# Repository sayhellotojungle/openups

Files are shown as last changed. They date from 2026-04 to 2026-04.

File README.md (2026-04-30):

# OpenUPS-ESP32S3

基于 ESP32-S3 的智能锂电池 UPS 控制系统，使用 BQ24780S 充电管理芯片与 BQ76920 电池监控芯片，支持 3-5 串锂离子/磷酸铁锂电池，12-19V 宽电压输入。

> **为什么不用铅酸 UPS？** 铅酸 UPS 待机功耗 10W+，体积笨重。本项目面向小功率主机、NAS、软路由、网络设备等场景，锂电池方案更小巧、更省电、更安静。

## 功能特性

### 核心功能

- **USB HID UPS** — ESP32-S3 原生 USB 接口，Windows/macOS/Linux 自动识别为标准 UPS 设备，支持低电量安全关机
- **充放电管理** — BQ24780S 充电控制，支持自适应充电电流、定时充电窗口（5 组周计划）、混合供电模式
- **电池管理** — BQ76920 电池监控，库仑计 SOC 计算、SOH 学习、自动均衡、多重保护（OV/UV/OCD/SCD/OT）
- **Web 仪表盘** — SPA 单页应用，macOS 风格 UI，实时 WebSocket 数据推送（3 秒间隔）
- **OTA 固件更新** — 网页拖拽上传固件，带签名校验，双分区安全升级
- **MQTT 集成** — Home Assistant 自动发现，支持 TLS 加密连接
- **Prometheus 监控** — `/metrics` 端点，可直接接入 Grafana

### 保护机制

| 保护类型 | 说明 |
|---|---|
| 过压保护 (OV) | 单体电压超阈值，切断充电 FET |
| 欠压保护 (UV) | 单体电压低于阈值，切断放电 FET |
| 过流保护 (OCD) | 放电电流超限 |
| 短路保护 (SCD) | 短路快速响应 |
| 过温保护 | 板载 + 环境温度双重检测 |
| 充电超时 | 防止异常长时间充电 |
| 系统状态机 | INIT → NORMAL → WARNING → CRITICAL 四级状态管理 |

## 硬件

### 关键参数

| 参数 | 值 |
|---|---|
| 输入电压 | 12-19V DC |
| 充电电流 | 最高 8128mA（BQ24780S） |
| 放电电流 | 最高 20A |
| 输入电流 | 最高 8064mA |
| 电池类型 | 3-5 串 Li-ion / LiFePO4 |
| 电流采样电阻 | 10mΩ（充电侧）/ 5mΩ（放电侧） |
| I2C 总线 | GPIO11(SDA) / GPIO12(SCL)，100kHz |

### ESP32 开发板

选择 **ESP32-S3 N16R8** 版本的开发板（16MB Flash / 8MB PSRAM）。插入时**注意核对引脚排列和插入方向**，反接可能损坏开发板或主板。

### 电池夹选择

电池组有条件的**尽量选择直接点焊成组**，接触电阻最小、最可靠。

如果使用电池夹，建议如下：

| 类型 | 材质 | 优缺点 |
|---|---|---|
| 插针电池夹 | 钢片 | 夹持力强，但**过紧**，拆装困难 |
| 贴片电池夹 | 铜材质 | 导电好，但**过松**，接触不可靠 |
| **贴片铜弹片 + 螺旋弹簧**（推荐） | 黄铜/紫铜 | 导电好，弹簧提供足够的回弹力，**推荐方案** |

推荐方案：[贴片铜弹片](https://item.taobao.com/item.htm?id=833701074625) + 线径 0.8mm × 外径 5mm × 长度 50mm 的螺旋弹簧配合使用。弹片负责导电，弹簧负责提供夹持力。

> **不建议使用钢片电池夹**，夹持力过大容易损伤电池外壳；纯铜弹片弹力不足，需要搭配螺旋弹簧。

### 硬件注意事项

- **电池选择** — 电池最好选择品质一致的，并保证初始电压一致。BQ76920 内置的平衡速度极慢，每天大概 20mV 不到。如果是大容量电池，要考虑在线路上增加外部平衡电路，BQ76920 也是支持的
- **R27、R66** — 正常情况下**不需要焊接**，这两个电阻用于选择 NTC 与隔离 I2C 芯片的供电源
- **I2C 隔离芯片** — PCB 设计使用 ISO1640BDR，也可以更换为 ISO1540DR。虽然 ISO1640 标称支持热拔插而 ISO1540 不支持，但实测 ISO1540DR 同样可以正常工作
- **SW_activate 按键** — 电池刚接入或 BQ76920 进入运输模式后，需要按下此按键一次激活芯片
- **SW_reset 按键** — 长按数秒进入 WiFi AP 模式（重置网络）；开机时持续按住则重新进入配置模式
- **H6、H7 跳线** — 使用 3S 电池需短接 H6，4S 电池需短接 H7（取决于电池串数），**请务必仔细确认后再上电**
- PCB 设计文件位于 `hardware/` 目录（EasyEDA Pro 格式）
- 3D 打印外壳基于贴片电路板设计，可直接打印使用（文件后续上传）

### 引脚定义

<details>
<summary>点击展开完整引脚表</summary>

| 功能 | GPIO | 说明 |
|---|---|---|
| **I2C** | | |
| I2C_SDA | 11 | I2C 数据线 |
| I2C_SCL | 12 | I2C 时钟线 |
| **BQ24780S** | | |
| ACOK | 13 | 电源适配器接入检测 |
| PROCHOT# | 14 | 芯片报警状态 |
| TB_STAT# | 15 | 混合供电状态 |
| IADP | 1 | 输入电流 ADC |
| IDCHG | 2 | 放电电流 ADC |
| PMON | 9 | 系统功率监控 ADC |
| **BQ76920** | | |
| ALERT | 16 | 电池管理报警中断 |
| I2C_VCC | 6 | I2C 隔离芯片供电控制 |
| **电压/温度** | | |
| INPUT_VOLTAGE | 4 | 输入电压（1:10 分压） |
| BATTERY_VOLTAGE | 5 | 电池电压（1:10 分压） |
| BOARD_TEMP | 7 | 板载温度（NTC 10K） |
| ENV_TEMP | 8 | 环境温度（NTC 10K） |
| TEMP_POWER | 21 | NTC 供电使能 |
| **LED 指示** | | |
| POWER_LED | 42 | 电源指示灯 |
| CHARGING_LED | 41 | 充电指示灯 |
| DISCHARGING_LED | 40 | 放电指示灯 |
| WIFI_FAIL_LED | 39 | WiFi 连接失败 |
| WIFI_OK_LED | 38 | WiFi 连接成功 |
| RGB_LED | 48 | WS2812B 可编程 RGB |
| **控制** | | |
| BUZZER | 18 | 蜂鸣器 |
| RESET_BTN | 17 | 重置按键（长按 2.5s+ 恢复出厂） |

</details>

## 快速开始

### 环境准备

1. 安装 [Arduino IDE](https://www.arduino.cc/en/software)
2. 安装 ESP32-S3 开发板支持包（Board Manager 搜索 `esp32`）
3. 安装所需库：

| 库名 | 用途 |
|---|---|
| ESPAsyncWebServer | 异步 Web 服务器 |
| AsyncTCP | 异步 TCP |
| ArduinoJson | JSON 序列化 |
| FastLED | WS2812B RGB LED |
| Preferences | NVS Flash 存储 |
| esp_task_wdt | 看门狗定时器 |
| **AsyncMQTT_ESP32** | MQTT 客户端（作者 khoih-prog，**请务必安装此版本**） |

> **注意**：MQTT 库请安装 **AsyncMQTT_ESP32**（作者 khoih-prog），不要安装其他 MQTT 库，API 不兼容。

### 编译烧录

1. 用 Arduino IDE 打开项目根目录的 `sketch_jan14a.ino`
2. 选择开发板：ESP32-S3 Dev Module，并按如下配置：

   | 选项 | 值 |
   |---|---|
   | USB CDC On Boot | **Disabled** |
   | Flash Mode | **QIO 80MHz** |
   | Flash Size | **16MB** |
   | Partition Scheme | **Custom**（使用项目自带的 `partitions.csv`） |
   | PSRAM | **OPI PSRAM** |
   | USB Mode | **USB-OTG** |

3. 编译并烧录

### OTA 更新

系统运行后，访问 `http://<设备IP>/update`，拖拽固件文件即可在线升级。固件需包含签名校验头。

## 首次使用

### 按键操作说明

| 按键 | 操作 | 效果 |
|---|---|---|
| **SW_activate** | 短按 | 激活 BQ76920（电池接入或退出运输模式后使用） |
| **SW_reset** | 长按数秒（运行中） | 重置网络配置，进入 WiFi AP 热点模式 |
| **SW_reset** | 开机时持续按住 | 重新进入初始配置模式（清除 NVS 配置） |

### 1. 硬件准备

1. 选择 **ESP32-S3 N16R8** 开发板，插入主板时注意引脚方向
2. 根据电池串数短接对应跳线：
   - 3S 电池 → 短接 **H6**
   - 4S 电池 → 短接 **H7**
   - 5S 电池 → 无需短接
3. 连接电池，按下 **SW_activate** 按键一次激活 BQ76920
4. 连接电源适配器（12-19V）

> **3S 电池用户注意**：3S 电池满电电压为 12.6V，如果使用 12V 电源适配器，由于充电芯片需要一定的压差才能工作，电池将无法充满。建议使用 **13V 左右**的电源适配器。当然，充不满也无大碍——锂电池保持 40%-80% 电量区间反而更有利于延长电池寿命。

### 2. 网络配置

刷机后首次启动（NVS 无配置时），系统自动进入配置模式：

1. 搜索并连接 WiFi 热点 **`OpenUPS-esp32`**（密码：`12345678`）
2. 浏览器访问 `http://192.168.4.1` 进入配置向导
3. 按向导依次配置：WiFi → 网络 → 电池参数 → 硬件 → MQTT（可选）
4. 配置完成后系统自动重启，连接到你配置的 WiFi 网络

> WiFi 热点密码可在代码中自行修改。如果需要重新进入配置模式，开机时**持续按住 SW_reset** 即可。

### 3. 电池保护参数配置

**系统启动后，务必在配置页面正确设置电池保护参数，所有单位均为 mV 和 mA：**

| 参数 | 说明 | 示例（3S NCM） |
|---|---|---|
| 电池串数 | 3 / 4 / 5 | 3 |
| 标称容量 | 电池标称容量 (mAh) | 2500 |
| 过压阈值 (OV) | 单体过压保护 (mV) | 4250 |
| 过压恢复 | 单体过压恢复 (mV) | 4150 |
| 欠压阈值 (UV) | 单体欠压保护 (mV) | 2800 |
| 欠压恢复 | 单体欠压恢复 (mV) | 3000 |
| 最大充电电流 | 充电电流上限 (mA) | 2000 |
| 最大放电电流 | 放电电流上限 (mA) | 5000 |
| 短路保护阈值 | 短路电流阈值 (mA) | 10000 |
| 过温阈值 | 过温保护温度 (°C) | 55 |

> **请务必根据你所使用的电池规格设置这些参数，错误的参数可能导致电池损坏或安全事故！**

## Web 界面

系统运行后，浏览器访问设备 IP 即可查看仪表盘：

- **状态总览** — SOC 进度条、电压/电流/温度、5 节电池电压（高亮最大/最小值）、均衡状态、充放电模式
- **BMS 状态** — 详细电池信息、电池电压统计、BQ76920 寄存器转储
- **电源状态** — 输入/输出功率、充电控制状态、BQ24780S 寄存器转储
- **系统配置** — WiFi、BMS 参数、充放电管理、定时充电窗口、硬件控制
- **ADC 校准** — 各 ADC 通道独立校准系数
- **固件升级** — OTA 在线更新

## API 接口

| 端点 | 方法 | 说明 |
|---|---|---|
| `/` | GET | Web 仪表盘 |
| `/api/status` | GET | 系统状态 JSON |
| `/api/bms` | GET | BMS 数据 JSON |
| `/api/power` | GET | 电源数据 JSON |
| `/metrics` | GET | Prometheus 文本格式指标 |
| `/api/calibration` | GET/POST | ADC 校准读写 |
| `/save` | POST | 保存配置 |
| `/firmware` | POST | OTA 固件上传 |
| `/bms/shipmode` | POST | 进入 BMS 运输模式 |
| `/ws` | WebSocket | 实时数据推送（3s 间隔） |

## 架构概览

```
┌─────────────────────────────────────────────────────────┐
│                    SystemManagement                      │
│              (FSM: INIT → NORMAL → WARNING → CRITICAL)  │
├──────────┬──────────┬──────────┬──────────┬─────────────┤
│   BMS    │  Power   │ Hardware │ WebServer│  WiFiManager│
│ (BQ76920)│(BQ24780S)│Interface │ + OTA    │   STA/AP    │
├──────────┴──────────┴──────────┴──────────┴─────────────┤
│                     EventBus (Pub/Sub)                   │
├─────────────────────────────────────────────────────────┤
│              Global State (Blackboard)                   │
│         System_Global_State (all telemetry)              │
├─────────────────────────────────────────────────────────┤
│            Driver Layer (I2C + CRC)                      │
│         BQ24780S Driver  |  BQ76920 Driver               │
└─────────────────────────────────────────────────────────┘
```

**额外服务：**
- **UPS HID Service** — USB HID 协议，主机识别为标准 UPS
- **MQTT Service** — Home Assistant 自动发现 + TLS 支持
- **ConfigManager** — NVS Flash 持久化所有配置

## 分区布局

| 分区 | 类型 | 大小 | 说明 |
|---|---|---|---|
| nvs | data | 20KB | 配置存储 |
| otadata | data | 8KB | OTA 数据 |
| app0 | app | 4.5MB | 固件槽 A |
| app1 | app | 4.5MB | 固件槽 B |
| coredump | data | 64KB | 崩溃转储 |
| spiffs | data | 6MB | 文件系统 |

## 目录结构

```
├── sketch_jan14a.ino          # 主程序入口
├── partitions.csv             # 分区表
├── src/
│   ├── bq24780s.h/.cpp        # BQ24780S 充电芯片驱动
│   ├── bq76920.h/.cpp         # BQ76920 电池监控驱动
│   ├── i2c_interface.h/.cpp   # I2C 通信（含 CRC）
│   ├── pins_config.h          # 引脚定义
│   ├── data_structures.h      # 数据结构定义
│   ├── hardware_interface.h/.cpp  # GPIO/ADC/LED/蜂鸣器/按键
│   ├── bms.h/.cpp             # 电池管理系统
│   ├── power_management.h/.cpp    # 充放电管理
│   ├── system_management.h/.cpp   # 系统状态机
│   ├── config_manager.h/.cpp  # NVS 配置管理
│   ├── web_server.h/.cpp      # HTTP/WebSocket/Prometheus/OTA
│   ├── WiFiManager.h/.cpp     # WiFi 管理
│   ├── event_bus.h            # 事件总线
│   ├── event_types.h          # 事件类型定义
│   ├── ups_hid_service.h/.cpp # USB HID UPS 服务
│   ├── mqtt_service.h/.cpp    # MQTT + HA 自动发现
│   ├── time_utils.h/.cpp      # NTP 时间管理
│   ├── utils.h/.cpp           # 工具函数
│   └── templates/             # Web UI 模板
│       ├── css_templates.h
│       ├── js_templates.h
│       └── page_templates.h
├── hardware/
│   └── ups.eprj2              # EasyEDA Pro 硬件设计文件
└── doc/                       # 芯片寄存器文档
```

## 已知限制

- 代码目前处于**测试版本**，部分功能尚未完善
- **暂时只支持三元锂电池（NCM/NCA）**，磷酸铁锂电池（LiFePO4）需要自行修改 `src/bms.h` 中的电压阈值与 SOC-OCV 电量对应表
- 硬件设计基于 EasyEDA Pro，暂无 KiCad 版本
- SOC 计算在电池首次使用时需要一次完整充放电循环进行校准

## 安全提示

> **本项目涉及锂电池充放电管理，操作不当可能存在安全风险。请确保你：**
> - 了解锂电池安全知识
> - 能够正确设置电池保护参数（OV/UV/OCD/SCD）
> - 有基本的电子电路调试能力
> - 能够承担实验风险
>
> 作者不对因使用本项目造成的任何损失负责。

## 参与贡献

欢迎提交 Issue 和 Pull Request！

AI 时代，人人都是高级程序员。无论是代码优化、Bug 修复、功能增强还是文档改进，都欢迎参与。

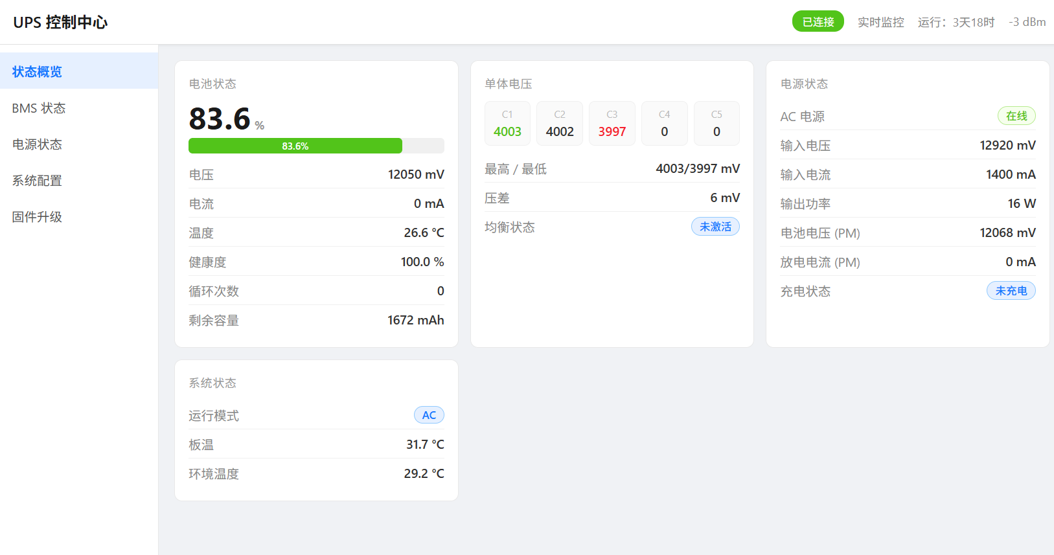
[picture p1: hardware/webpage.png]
webpage


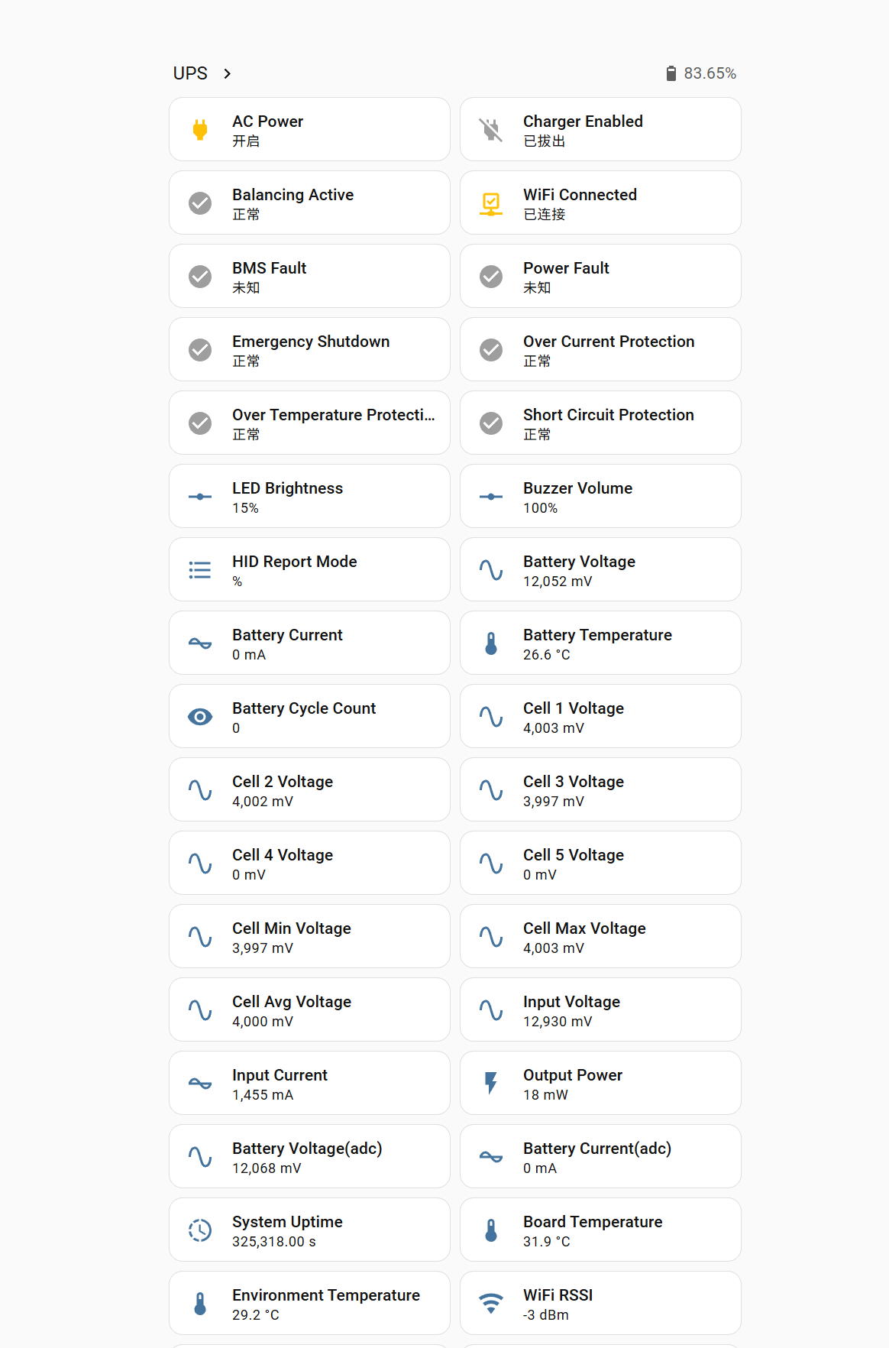
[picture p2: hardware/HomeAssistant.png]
HomeAssistant


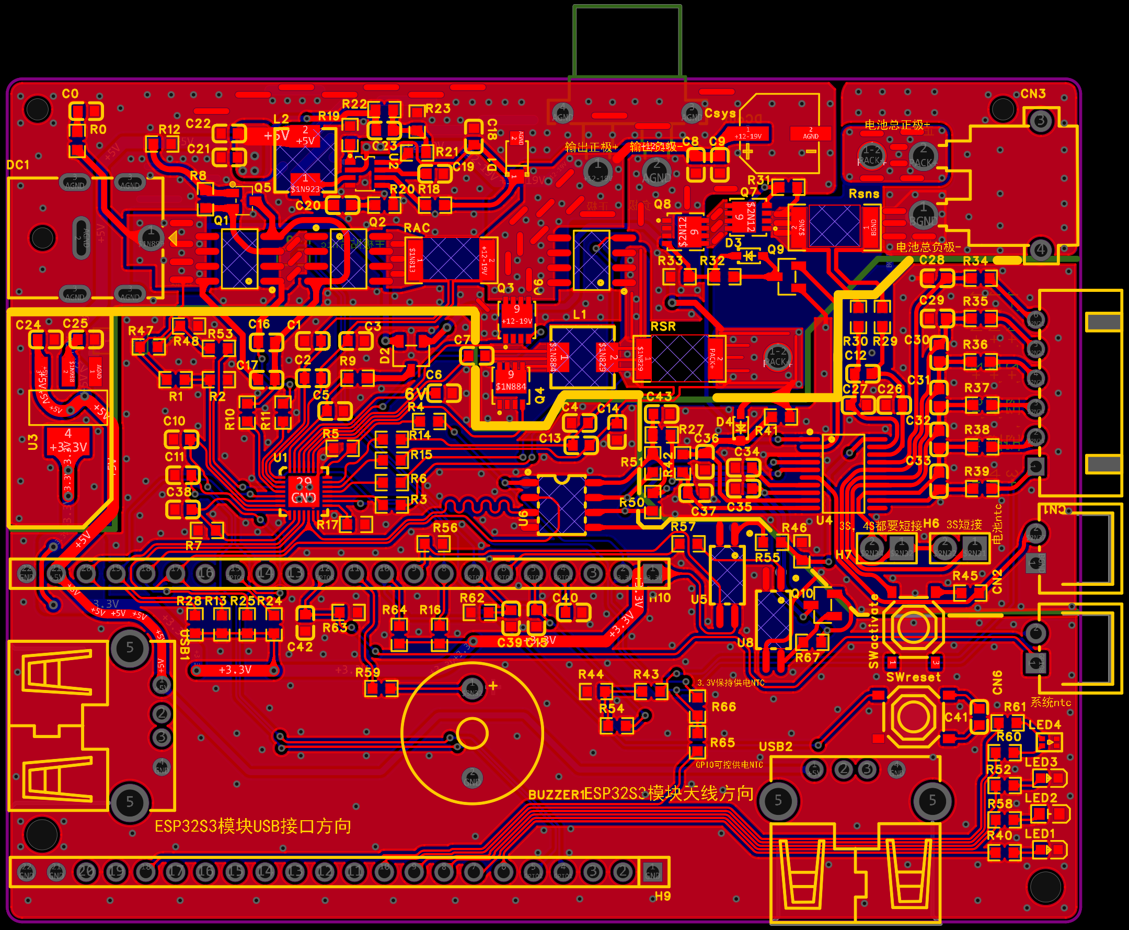
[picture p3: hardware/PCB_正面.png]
PCB_正面


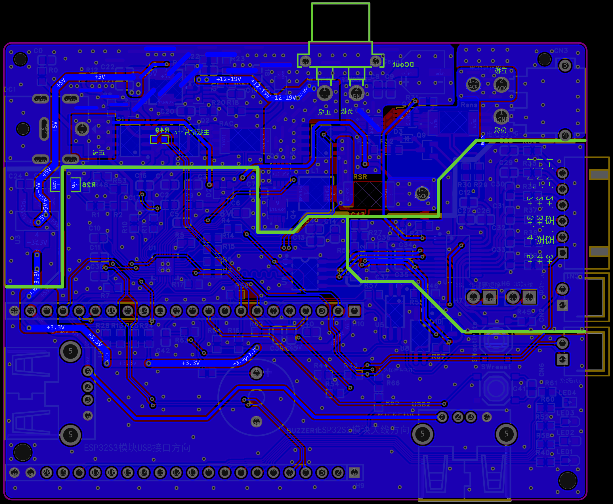
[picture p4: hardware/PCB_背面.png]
PCB_背面


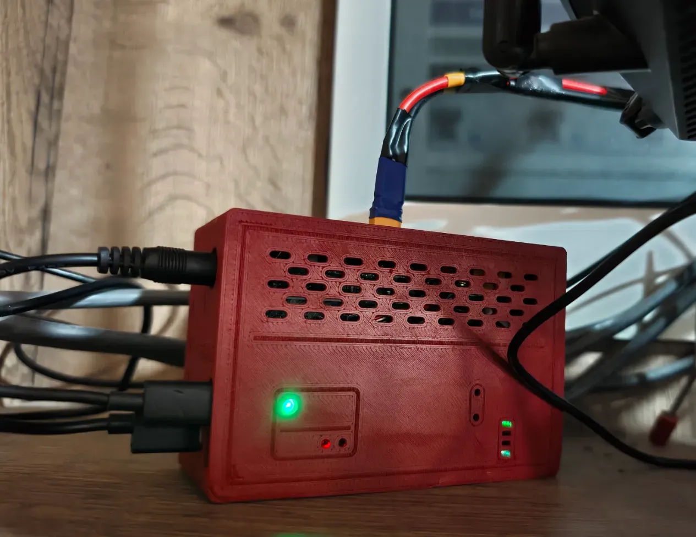
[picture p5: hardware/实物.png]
实物


实物1

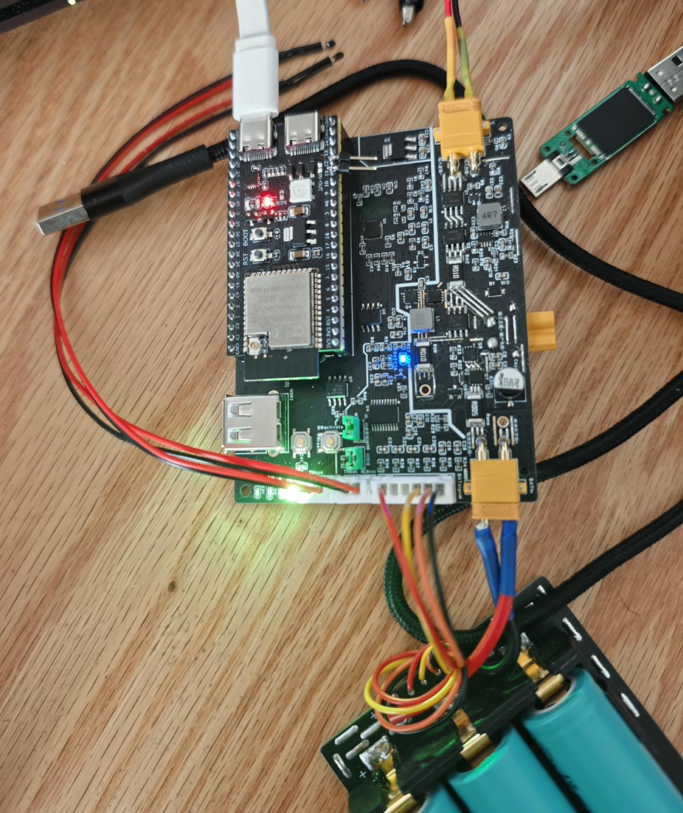
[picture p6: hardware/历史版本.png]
历史版本


## 致谢

本项目从硬件设计到嵌入式软件开发，几乎全部由 AI 辅助完成。作者此前没有任何硬件开发和嵌入式编程经验，没有 AI 的帮助，这个项目不可能实现。

特别感谢：

- **阿里巴巴通义千问（Qwen）**
- **小米 MiMo 大模型**

排名不分先后，都是伟大的公司！

AI 时代，人人都是高级程序员。

## 许可证

本项目为开源项目，详见仓库许可信息。

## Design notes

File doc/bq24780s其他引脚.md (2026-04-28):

这六个引脚（`ACOK`、`PROCHOT#`、`TB_STAT#`、`IADP`、`IDCHG`、`PMON`）主要负责**电源状态监控**、**系统保护**以及**CPU交互**。它们是 bq24780S 与主机系统（EC/BIOS）沟通电源健康状况的关键通道。

以下是基于文档的详细解释：

### 1. ACOK- 适配器正常指示

这是一个**输出信号**，用于告诉系统“适配器电源是否有效且稳定”。

- **功能**：适配器检测开漏输出（Open Drain Output）。
- **工作逻辑**：
  - **高电平（有效）**：当 `ACDET` 引脚电压高于 2.4V（且 `VCC` 在正常范围内，高于 UVLO 但低于过压值）时，内部 MOSFET 断开，引脚通过外部上拉电阻变高。这表示适配器已连接且电压正常，系统可以开启 ACFET 供电。
  - **低电平（无效）**：如果适配器电压过低、过高或未连接，内部 MOSFET 导通，引脚被拉低。
- **关键细节**：内部有一个约 150ms（首次插入）或 1.3s（后续插入）的延时（Debounce），防止插拔瞬间的抖动导致信号误判。

### 2. PROCHOT# - 处理器过热/过载指示

这是一个**输出信号**（低电平有效），用于通知 CPU 降低功耗（Throttling）。它是系统保护的最后一道防线。

- **功能**：开漏输出，主动向 CPU 发送“降频”请求。
- **触发条件**（任一满足即触发）：
  - **ICRIT**：适配器峰值电流超过设定值（默认 150%）。
  - **INOM**：适配器平均电流超过设定值（默认 110%）。
  - **IDCHG**：电池放电电流过大。
  - **VSYS**：系统电压过低（跌落）。
  - **事件**：适配器突然拔掉（ACOK 变低）或电池突然拔掉（BATPRES 变高）。
- **动作**：一旦触发，`PROCHOT#` 会拉低至少 **10ms**（默认），强制 CPU 降低频率以减少系统功耗，防止适配器过载或系统崩溃。

### 3. TB_STAT#  - 涡轮/升压模式状态

这是一个**输出信号**（低电平有效），用于指示芯片当前是否处于**混合动力升压模式**（Hybrid Power Boost Mode，文档中也称 Turbo Boost）。

- **功能**：升压模式指示。
- **状态含义**：
  - **低电平（Active）**：芯片正处于升压模式。这意味着系统需求功率超过了适配器的供应能力，电池正在放电以辅助供电。
  - **高电平（Inactive）**：芯片处于正常的充电模式（仅适配器供电）。
- **应用场景**：系统可以通过读取这个引脚的状态来判断是否处于高负载状态（如游戏或渲染时 CPU/GPU 满载）。

### 4. IADP  - 适配器电流监测输出

这是一个**模拟电压输出**，用于实时反映**输入电流**的大小。

- **功能**：适配器电流缓冲输出。
- **计算公式**：
  - VIADP=G×(VACP−VACN)*V**I**A**D**P*=*G*×(*V**A**CP*−*V**A**CN*)
  - **增益 (G)**：可通过 SMBus 在 20x 或 40x 之间选择（默认 20x）。
- **用途**：主机（EC）可以通过 ADC 读取这个电压，计算出当前从适配器取用了多少电流。用于系统功耗管理或在 `PROCHOT` 触发前进行预判。

### 5. IDCHG  - 电池放电电流监测输出

这是一个**模拟电压输出**，专门用于监测**电池放电**时的电流。

- **功能**：放电电流缓冲输出。
- **计算公式**：
  - VIDCHG=G×(VSRN−VSRP)
  - **增益 (G)**：可通过 SMBus 在 8x 或 16x 之间选择（默认 16x）。
- **用途**：
  - 监测电池当前是充电还是放电。
  - 在混合升压模式下，监测电池输出了多少电流。
  - 作为 `PROCHOT` 信号的触发源之一（防止电池放电过流）。

### 6. PMON  - 系统总功率监测输出

这是一个**模拟电流/电压输出**，用于反映系统的**总功率**。

- **功能**：系统功率监测。
- **工作原理**：
  - 引脚输出的是**电流**，通常需要外接一个电阻接地转换为电压。
  - 输出电流与“适配器输入功率”和“电池充放电功率”的总和成正比。
- **比例因子**：
  - 默认为 **1 μA/W**（可通过 SMBus 寄存器 `ChargeOption1` (0x3B) Bit 9 修改）。
  - 例如：当系统总功率为 45W 时，输出电流约为 45μA。若负载电阻为 100kΩ，则输出电压为 4.5V（需注意电压钳位在 3.3V 左右）。
- **用途**：提供系统总能耗数据，帮助系统进行更全面的功耗预算管理。

### ILIM --硬件限制充放电电流

| ILIM 电压 ( $ V_{ILIM} $ ) | 充电电流限制 ( $ I_{CHG} $ ) | 放电电流限制 ( $ I_{DIS} $ ) | 状态说明 |
| --- | --- | --- | --- |
| 0 mV - 60 mV | 0 A | 0 A | 禁止 (Converter Disabled) |
| 75 mV | 375 mA | 1.5 A | 软件限制优先于此值 |
| 100 mV | 500 mA | 2.0 A | 软件限制优先于此值 |
| 120 mV | 600 mA | 2.4 A | 开启阈值 (Converter Enable) |
| 200 mV | 1.0 A | 4.0 A | 典型限制值 |
| 400 mV | 2.0 A | 8.0 A | 常用限制值 |
| 500 mV | 2.5 A | 10.0 A | - |
| 800 mV | 4.0 A | 16.0 A | - |
| 1000 mV (1V) | 5.0 A | 20.0 A | - |
| 1600 mV (1.6V) | 8.0 A | 32.0 A | 放电上限 (Discharge Max) |
| > 2000 mV (2V) | 寄存器设定值 | 寄存器设定值 | 失效 (Disabled, 软件控制优先) |

### 总结表格

表格

| 引脚名称 | I/O类型 | 信号性质 | 核心功能 |
| :--- | :--- | :--- | :--- |
| **ACOK** | Output  | 数字 (开漏) | 适配器是否连接正常 |
| **PROCHOT#** | Output  | 数字 (低有效) | 紧急通知 CPU 降频 (过流/过压/欠压) |
| **TB_STAT#** | Output  | 数字 (低有效) | 指示是否处于“电池+适配器”同时供电模式 |
| **IADP** | Output  | 模拟电压 | 输出与适配器电流成比例的电压 |
| **IDCHG** | Output  | 模拟电压 | 输出与电池放电电流成比例的电压 |
| **PMON** | Output  | 模拟电流/电压 | 输出与系统总功率成比例的信号 |

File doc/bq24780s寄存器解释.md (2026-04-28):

### Table 4. Battery Charger Command Summary

| 地址  | 寄存器名称 | 表号 | 读/写 | 描述 | 复位状态 (POR State) |
| :---- | :--- | :--- | :--- | :--- | :--- |
| 0x12H | ChargeOption0() | Table 5  | Read or Write | Charge Options Control 0 | 0xE108H |
| 0x3BH | ChargeOption1() | Table 6  | Read or Write | Charge Options Control 1 | 0xC210H |
| 0x38H | ChargeOption2() | Table 7  | Read or Write | Charge Options Control 2 | 0x0384H |
| 0x37H | ChargeOption3() | Table 8  | Read or Write | Charge Options Control 3 | 0x1A40H |
| 0x3CH | ProchotOption0() | Table 9  | Read or Write | PROCHOT Options Control 0 | 0x4A54H |
| 0x3DH | ProchotOption1() | Table 10 | Read or Write | PROCHOT Options Control 1 | 0x8120H |
| 0x3AH | ProchotStatus() | Table 11 | Read Only | PROCHOT status | 0x0000H |
| 0x14H | ChargeCurrent() | Table 12 | Read or Write | 7-bit Charge Current Setting | 0x0000H |
| 0x15H | ChargeVoltage() | Table 13 | Read or Write | 11-bit Charge Voltage Setting | 0x0000H |
| 0x39H | DischargeCurrent() | Table 15 | Read or Write | 6-bit Discharge Current Setting | 0x1800H, or 6144mA |
| 0x3FH | InputCurrent() | Table 14 | Read or Write | 6-bit Input Current Setting | 0x1000H, or 4096mA |
| 0xFEH | ManufacturerID() | - | Read Only | Manufacturer ID | 0x0040H |
| 0xFFH | DeviceID() | - | Read Only | Device ID | 0x30H |

### 表5. ChargeOption0 寄存器 (0x12H)

| 位域 | 位名称 | 描述 |
| :--- | :--- | :--- |
| **[15]** | **Low Power Mode Enable**<br>(EN_LWPWR) | **0:** IC 仅在电池模式下以性能模式运行。PROCHOT、电流/功率监视器缓冲器和独立比较器遵循寄存器设置。<br>**1:** IC 仅在电池模式下以低功耗模式运行。当此位使能时，IC 处于最低静态电流。PROCHOT、放电电流监视器缓冲器、功率监视器缓冲器和独立比较器均被禁用。<br>**（复位后默认）** |
| **[14:13]** | **WATCHDOG 定时器调整**<br>(WDTMR_ADJ) | 设置连续 SMBus 写充电电压或充电电流命令之间的最大延迟。如果 IC 在看门狗时间段内未接收到对 REG0x14() 或 REG0x15() 的写操作，充电器转换器将停止以禁用充电和升压模式操作。过期后，定时器将在写入 REG0x14() 或 REG0x15() 时恢复。如果所有其他条件有效，充电或升压操作将恢复。<br>**00:** 禁用看门狗定时器<br>**01:** 启用，5 秒<br>**10:** 启用，88 秒<br>**11:** 启用看门狗定时器 (175 秒) **（复位后默认）** |
| **[12:10]** | **Reserved** | **0 - 保留** |
| **[9:8]** | **Switching Frequency**<br>(PWM_FREQ) | 转换器开关频率。<br>**00:** 600 kHz<br>**01:** 800 kHz **（复位后默认）**<br>**10:** 1 MHz<br>**11:** 保留 |
| **[7:6]** | **Reserved** | **0 - 保留** |
| **[5]** | **LEARN Mode Enable**<br>(EN_LEARN) | 电池 LEARN 模式使能。在 LEARN 模式下，ACFET 和 RBFET 关断，BATFET 导通。当 /BATPRES 为高电平时，IC 退出 LEARN 模式，此位被置回 0。当电池耗尽时，充电器无法使能 LEARN 模式。<br>**0:** 禁用 LEARN 模式 **（复位后默认）**<br>**1:** 使能 LEARN 模式 |
| **[4]** | **IADP Amplifier Gain for Primary Input**<br>(IADP_GAIN) | IADP 引脚电压与 ACP 和 ACN 之间电压的比值。<br>**0:** 20X **（复位后默认）**<br>**1:** 40X |
| **[3]** | **IDCHG Amplifier Gain**<br>(IDCHG_GAIN) | IDCHG 引脚电压与 SRN 和 SRP 之间电压的比值。<br>**0:** 8x，放电电流调节范围 0-32A。<br>**1:** 16x，放电电流调节范围 **（复位后默认）** |
| **[2:1]** | **Reserved** | **0 - 保留** |
| **[0]** | **Charge Inhibit**<br>(CHRG_INHIBIT) | 充电抑制。当此位为 0 时，如果 REG0x14() 和 REG0x15() 中有有效值，则使能电池充电。<br>**0:** 使能充电 **（复位后默认）**<br>**1:** 抑制充电 |

### 表6. ChargeOption1 寄存器 (0x3BH)

| 位域 | 位名称 | 描述 |
| :--- | :--- | :--- |
| **[15:14]** | **Battery Depletion Threshold**<br>(BAT_DEPL_VTH) | 电池欠压阈值。在 LEARN 周期中，当电池电压低于耗尽阈值时，IC 退出 LEARN 模式。在升压模式中，当电池电压低于耗尽阈值时，IC 退出升压模式。<br>**00:** 下降阈值 = 电压调节限制的 59.19% (~2.486V/电芯)<br>**01:** 下降阈值 = 电压调节限制的 62.65% (~2.631V/电芯)<br>**10:** 下降阈值 = 电压调节限制的 66.55% (~2.795V/电芯)<br>**11:** 下降阈值 = 电压调节限制的 70.97% (2.981V/电芯) **（复位后默认）** |
| **[13:12]** | **(RSNS_RATIO)** | 使用不同的输入采样电阻 RAC 和充电采样电阻 RSR 调整 PMON 计算。<br>**00:** RAC 和 RSR 1:1 **（复位后默认）**<br>**01:** RAC 和 RSR 2:1<br>**10:** RAC 和 RSR 1:2<br>**11:** 保留 |
| **[11]** | **EN_IDCHG** | IDCHG 引脚输出使能。<br>**0:** 禁用 IDCHG 输出以最小化静态电流 (Iq) **（复位后默认）**<br>**1:** 使能 IDCHG 输出 |
| **[10]** | **EN_PMON** | PMON 引脚输出使能。<br>**0:** 禁用 PMON 输出以最小化静态电流 (Iq) **（复位后默认）**<br>**1:** 使能 PMON 输出 |
| **[9]** | **PMON Gain**<br>(PMON_RATIO) | PMON 输出电流与总输入和电池功率的比率（使用 10 mΩ 采样电阻）。<br>**0:** 0.25 μA/W<br>**1:** 1 μA/W **（复位后默认）**<br>当采样电阻为 20/10 mΩ，或 10/20 mΩ，或 20/20 mΩ (RAC 和 RSR) 时：<br>**0:** 0.5 μA/W<br>**1:** 2 μA/W **（复位后默认）** |
| **[8]** | **Reserved** | **0 - 保留** |
| **[7]** | **Independent Comparator**<br>Reference (CMP_REF) | 独立比较器内部参考电压。<br>**0:** 2.3 V **（复位后默认）**<br>**1:** 1.2 V |
| **[6]** | **Independent Comparator**<br>Polarity (CMP_POL) | 独立比较器输出极性。<br>**0:** 当 CMPIN 高于内部阈值时，CMPOUT 为低电平 **（复位后默认）**<br>**1:** 当 CMPIN 高于内部阈值时，CMPOUT 为高电平 |
| **[5:4]** | **Independent Comparator**<br>Deglitch Time (CMP_DEG) | 独立比较器去抖时间，应用于 CMPOUT 变低的边沿。不适用于 CMPOUT 上升沿。<br>**00:** 禁用独立比较器<br>**01:** 使能独立比较器，输出去抖时间 1 μs **（复位后默认）**<br>**10:** 使能独立比较器，输出去抖时间 2 ms<br>**11:** 使能独立比较器，输出去抖时间 5 sec |
| **[3]** | **Power Path Latch-off Enable**<br>(EN_FET_LATCHOFF)  | 当独立比较器触发时，ACFET/RBFET 关断。锁定解除方式：上电复位 (POR) 或将此位写为 0。<br>**0:** 当独立比较器触发时，无电源路径锁定关闭 **（复位后默认）**<br>**1:** 当独立比较器触发时，电源路径锁定关闭。 |
| **[2]** | **Reserved** | **0 - 保留** |
| **[1]** | **Discharge SRN for Shipping Mode**<br>(EN_SHIP_DCHG) | 以最小 5-mA 电流为 SRN 引脚放电 140 ms。140 ms 后，此位被重置为 0。<br>**0:** 禁用放电模式 **（复位后默认）**<br>**1:** 使能放电模式 |
| **[0]** | **Reserved** | **0 - 保留** |

### 表7. ChargeOption2 寄存器 (0x38H)

| 位域 | 位名称 | 描述 |
| --- | --- | --- |
| **[15:10]** | **Reserved** | **0 – 保留** |
| **[9:8]** | **Reserved** | **1 - 保留** |
| **[7]** | **External Current Limit Enable** (EN_EXTILIM) | 外部 ILIM 引脚使能，用于设置充电和放电电流。 **0:** 充电/放电电流限制由 REG0x14() 和 REG0x39() 设置。 **1:** 充电/放电电流限制由 ILIM 引脚和寄存器设置的较低值决定。 **（复位后默认）** |
| **[6:3]** | **Reserved** | **0 - 保留** |
| **[2]** | **Reserved** | **1 - 保留** |
| **[1:0]** | **Reserved** | **0 - 保留** |

### 表8. ChargeOption3 寄存器 (0x37H)

| 位域 | 位名称 | 描述 |
| --- | --- | --- |
| **[15]** | **Discharge Current Regulation Enable** (EN_IDCHG_REG) | 电池放电电流调节使能。 **0:** 禁用放电电流调节 **（复位后默认）** **1:** 使能放电电流调节 |
| **[14:13]** | **Reserved** | **0 - 保留** |
| **[12]** | **ACOK Deglitch Time for Primary Input** (ACOK_DEG) | 调整 ACOK 上升沿去抖时间。 上电复位 (POR) 后，第一次插入适配器时，去抖时间始终为 150 ms，与寄存器位无关。从第二次插入适配器开始，去抖时间遵循位设置。当系统过流或系统短路导致 ACDET 被拉低至 2.4 V 以下时，1.3 秒去抖时间使 ACFET/RBFET 在下次开启前保持关闭足够长时间。 **0:** ACOK 上升沿去抖时间 150ms **1:** ACOK 上升沿去抖时间 1.3 sec **（复位后默认）** |
| **[11]** | **Adapter Present Indicator** (ACOK_STAT) | 输入存在指示。逻辑与 ACOK 引脚相同。此位为只读。 **0:** AC 适配器不存在 **1:** AC 适配器存在 |
| **[10]** | **ACOC Enable** (EN_ACOC) | 通过监测 ACP_ACN 电压进行 ACOC 保护。 **0:** 禁用 ACOC **（复位后默认）** **1:** 使能 ACOC |
| **[9]** | **ACOC Limit** (ACOC_VTH) | ACOC 保护阈值，通过监测 ACP_ACN 电压设置。 **0:** ICRIT 的 125% **1:** ICRIT 的 200% **（复位后默认）** |
| **[8]** | **Reserved** | **0 – 保留** |
| **[7]** | **HSFET VDS Threshold** (IFAULT_HI) | 通过监测高侧 MOSFET 漏源电压进行 MOSFET/电感短路保护。 **0:** 禁用 **（复位后默认）** **1:** 750 mV |
| **[6]** | **LSFET VDS Threshold** (IFAULT_LO) | 通过监测低侧 MOSFET 漏源电压进行 MOSFET/电感短路保护。也可作为升压功能期间的逐周期电流限制阈值。 **0:** 禁用 **1:** 250 mV **（复位后默认）** |
| **[5]** | **Fast DPM Threshold** (FDPM_VTH) | 快速 DPM 比较器阈值，用于进入混合电源升压模式。（升压模式的最小 DPM 设置：1536 mA） **0:** 107% (下降 93%) **（复位后默认）** **1:** 115% (下降 85%) |
| **[4:3]** | **Fast DPM Deglitch Time** (FDPM_DEG) | 从系统电流超过快速 DPM 阈值到电池放电进入升压模式的响应时间。 **00:** 响应时间 150 μs **（复位后默认）** **01:** 响应时间 250 μs **1X:** 响应时间 50 μs |
| **[2]** | **Hybrid Power Boost Mode Enable** (EN_BOOST) | 升压模式使能位。当 /BATPRES 从低电平变为高电平（电池移除）时，此位将被重置为零以禁用升压模式。 **0:** 禁用混合电源升压模式 **（复位后默认）** **1:** 使能混合电源升压模式 |
| **[1]** | **Boost Mode Indication** (BOOST_STAT) | 升压模式指示器。当设备处于升压模式时，此位变为低电平。此位为只读。 **0:** 充电器不在混合电源升压模式 **（复位后默认）** **1:** 充电器在混合电源升压模式 |
| **[0]** | **Reserved** | **0 – 保留** |

### 表9. ProchotOption0 寄存器 (0x3CH)

| 位域 | 位名称 | 描述 |
| --- | --- | --- |
| **[15:11]** | **ICRIT Threshold** (ICRIT_VTH) | 5 位，REG0x3F() 中 IDPM 的百分比。测量通过 ACP 和 ACN 的电流。当电流高于此阈值时触发。 **00000:** 110% **00001:** 110% **00010:** 115% **00011:** 120% …. **10010:** 195% **10011:** 200% **10100:** 205% **10101:** 210% **10110:** 215% **10111:** 220% **11000:** 225% **11001:** 230% **11010:** 250% **11011:** 300% **11100:** 350% **11101:** 400% **11110:** 450% **11111:** 超出范围 步进: 5%, 默认值: 150% (01001) |
| **[10:9]**  | **ICRIT Deglitch time** (ICRIT_DEG) | 典型 ICRIT 去抖时间。 **00:** 10 μs **01:** 100 μs **（复位后默认）** **10:** 400 μs **11:** 800 μs |
| **[8]** | **Reserved** | **0 – 保留** |
| **[7:6]** | **VSYS Threshold** (VSYS_VTH) | 在 SRN 上测量，固定 20-μs 去抖时间。当 SRN 电压低于阈值时触发。 如果 REG0x15() 编程值低于 VSYS 阈值，建议不要在 PROCHOT 配置中使能 VSYS。 **00:** 5.75 V **01:** 6 V **（复位后默认）** **10:** 6.25 V **11:** 6.5 V |
| **[5]** | **PROCHOT Pulse Extension Enable** (EN_PROCHOT_EXT) | 当脉冲扩展使能时，保持 PROCHOT 引脚电压为低电平，直到主机写 0x3C[2] = 0。 **0:** 禁用脉冲扩展 **（复位后默认）** **1:** 使能脉冲扩展 |
| **[4:3]** | **PROCHOT Pulse Width** (PROCHOT_WIDTH) | 当 REG0x3C[5]=0 时的最小 PROCHOT 脉冲宽度。 **00:** 100 μs **01:** 1 ms **10:** 10 ms **（复位后默认）** **11:** 5 ms |
| **[2]** | **PROCHOT Pulse Clear** (PROCHOT_CLEAR) | 当 (0x3C[5] = 1) 时清除 PROCHOT 脉冲。 **0:** 清除 PROCHOT 脉冲并将 PROCHOT 引脚驱动为高电平 **1:** 空闲 **（复位后默认）** |
| **[1]** | **INOM Deglitch Time** (INOM_DEG) | 最大 INOM 去抖时间。INOM 阈值是 REG0x3F() 中 IDPM 的 110%。测量 ACP 和 ACN 之间的电流。当电流高于此阈值时触发。 **0:** 1 ms (必须是最大值) **（复位后默认）** **1:** 60 ms (最大值) |
| **[0]** | **Reserved** | **0 - 保留** |

### 表10. ProchotOption1 寄存器 (0x3DH)

| 位域 | 位名称 | 描述 |
| --- | --- | --- |
| **[15:10]** | **IDCHG Threshold** (IDCHG_VTH) | 6 位，范围 0 A 至 32256 mA，步进 512 mA。测量 SRN 和 SRP 之间的电流。当放电电流高于阈值时触发。 **默认:** 16384 mA (100000) |
| **[9:8]** | **IDCHG Deglitch Time** (IDCHG_DEG) | 典型 IDCHG 去抖时间。 **00:** 1.6 ms **01:** 100 μs **（复位后默认）** **10:** 6 ms **11:** 12 ms |
| **[7]** | **Reserved** | **0 - 保留** |
| **[6:0]** | **PROCHOT input current envelop selector** (PROFILE) | 当适配器存在时，PROCHOT 功能由以下位使能。 当适配器移除时，PROCHOT 配置中的 ICRIT、INOM、BATPRES 和 ACOK 功能自动禁用。比较器、IDCHG 和 VSYS 功能设置保留。当所有位为 0 时，PROCHOT 功能禁用。 **位 6:** 独立比较器, 0: 禁用 **（复位后默认）**; 1: 使能 **位 5:** ICRIT, 0: 禁用; 1: 使能 **（复位后默认）** **位 4:** INOM, 0: 禁用 **（复位后默认）**; 1: 使能 **位 3:** IDCHG, 0: 禁用 **（复位后默认）**; 1: 使能 **位 2:** VSYS, 0: 禁用 **（复位后默认）**; 1: 使能 **位 1:** BATPRES, 0: 禁用 **（复位后默认）**; 1: 使能 (单次上升沿触发) **位 0:** ACOK, 0: 禁用 **（复位后默认）**; 1: 使能 (单次下降沿触发) |

### 表11. ProchotStatus 寄存器 (0x3AH)

| 位域 | 位名称 | 描述 |
| --- | --- | --- |
| **[15:7]** | **Reserved** | **0 - 保留** |
| **[6:0]**  | **PROCHOT status** (Read only) | 在同一 PROCHOT 脉冲期间触发的所有事件的状态均设置为 1。寄存器在以下任一条件发生时重置： • 主机在 PROCHOT 变高后首次读取 • PROCHOT 变低以开始另一个脉冲。 **位 6:** 独立比较器, 0: 未触发; 1: 触发 **位 5:** ICRIT, 0: 未触发; 1: 触发 **位 4:** INOM, 0: 未触发; 1: 触发 **位 3:** IDCHG, 0: 未触发; 1: 触发 **位 2:** VSYS, 0: 未触发; 1: 触发 **位 1:** BATPRES, 0: 未触发; 1: 触发 **位 0:** ACOK, 0: 未触发; 1: 触发 |

### 表12. Charge Current 寄存器 (0x14H)，使用 10-mΩ 采样电阻

| 位域 | 位名称 | 描述 |
| --- | --- | --- |
| **0**  | Not used | 值忽略 |
| **1**  | Not used | 值忽略 |
| **2**  | Not used | 值忽略 |
| **3**  | Not used | 值忽略 |
| **4**  | Not used | 值忽略 |
| **5**  | Not used | 值忽略 |
| **6**  | **Charge Current, DACICHG 0** | 0 = 增加 0 mA 的充电器电流 1 = 增加 64 mA 的充电器电流 |
| **7**  | **Charge Current, DACICHG 1** | 0 = 增加 0 mA 的充电器电流 1 = 增加 128 mA 的充电器电流  |
| **8**  | **Charge Current, DACICHG 2** | 0 = 增加 0 mA 的充电器电流 1 = 增加 256 mA 的充电器电流  |
| **9**  | **Charge Current, DACICHG 3** | 0 = 增加 0 mA 的充电器电流 1 = 增加 512 mA 的充电器电流  |
| **10** | **Charge Current, DACICHG 4** | 0 = 增加 0 mA 的充电器电流 1 = 增加 1024 mA 的充电器电流 |
| **11** | **Charge Current, DACICHG 5** | 0 = 增加 0 mA 的充电器电流 1 = 增加 2048 mA 的充电器电流 |
| **12** | **Charge Current, DACICHG 6** | 0 = 增加 0 mA 的充电器电流 1 = 增加 4096 mA 的充电器电流 |
| **13** | Not used | 1 = 无效写入 |
| **14** | Not used | 1 = 无效写入 |
| **15** | Not used | 1 = 无效写入 |

### 表13. Charge Voltage 寄存器 (0x15H)

| 位域 | 位名称 | 描述 |
| --- | --- | --- |
| **0**  | Not used | 值忽略 |
| **1**  | Not used | 值忽略 |
| **2**  | Not used | 值忽略 |
| **3**  | Not used | 值忽略 |
| **4**  | **Charge voltage, DACV 0**  | 0 = 增加 0 mV 的充电器电压 1 = 增加 16 mV 的充电器电压 |
| **5**  | **Charge voltage, DACV 1**  | 0 = 增加 0 mV 的充电器电压 1 = 增加 32 mV 的充电器电压 |
| **6**  | **Charge voltage, DACV 2**  | 0 = 增加 0 mV 的充电器电压 1 = 增加 64 mV 的充电器电压 |
| **7**  | **Charge voltage, DACV 3**  | 0 = 增加 0 mV 的充电器电压 1 = 增加 128 mV 的充电器电压 |
| **8**  | **Charge voltage, DACV 4**  | 0 = 增加 0 mV 的充电器电压 1 = 增加 256 mV 的充电器电压 |
| **9**  | **Charge voltage, DACV 5**  | 0 = 增加 0 mV 的充电器电压 1 = 增加 512 mV 的充电器电压 |
| **10** | **Charge voltage, DACV 6**  | 0 = 增加 0 mV 的充电器电压 1 = 增加 1024 mV 的充电器电压  |
| **11** | **Charge voltage, DACV 7**  | 0 = 增加 0 mV 的充电器电压 1 = 增加 2048 mV 的充电器电压  |
| **12** | **Charge voltage, DACV 8**  | 0 = 增加 0 mV 的充电器电压 1 = 增加 4096 mV 的充电器电压  |
| **13** | **Charge voltage, DACV 9**  | 0 = 增加 0 mV 的充电器电压 1 = 增加 8192 mV 的充电器电压  |
| **14** | **Charge voltage, DACV 10** | 0 = 增加 0 mV 的充电器电压 1 = 增加 16384 mV 的充电器电压 |
| **15** | Not used | 1 = 无效写入 |

### 表14. Input Current 寄存器 (0x3FH)，使用 10-mΩ 采样电阻

| 位域 | 位名称 | 描述 |
| --- | --- | --- |
| **0**  | Not used | 值忽略 |
| **1**  | Not used | 值忽略 |
| **2**  | Not used | 值忽略 |
| **3**  | Not used | 值忽略 |
| **4**  | Not used | 值忽略 |
| **5**  | Not used | 值忽略 |
| **6**  | Not used | 值忽略 |
| **7**  | **Input current, DACIIN 0** | 0 = 增加 0 mA 的输入电流 1 = 增加 128 mA 的输入电流  |
| **8**  | **Input current, DACIIN 1** | 0 = 增加 0 mA 的输入电流 1 = 增加 256 mA 的输入电流  |
| **9**  | **Input current, DACIIN 2** | 0 = 增加 0 mA 的输入电流 1 = 增加 512 mA 的输入电流  |
| **10** | **Input current, DACIIN 3** | 0 = 增加 0 mA 的输入电流 1 = 增加 1024 mA 的输入电流 |
| **11** | **Input current, DACIIN 4** | 0 = 增加 0 mA 的输入电流 1 = 增加 2048 mA 的输入电流 |
| **12** | **Input current, DACIIN 5** | 0 = 增加 0 mA 的输入电流 1 = 增加 4096 mA 的输入电流 |
| **13** | Not used | 1 = 无效写入 |
| **14** | Not used | 1 = 无效写入 |
| **15** | Not used | 1 = 无效写入 |

### 表15. Discharge Current 寄存器 (0x39H)，使用 10-mΩ 采样电阻

| 位域 | 位名称 | 描述 |
| --- | --- | --- |
| **0**  | Not used | 值忽略 |
| **1**  | Not used | 值忽略 |
| **2**  | Not used | 值忽略 |
| **3**  | Not used | 值忽略 |
| **4**  | Not used | 值忽略 |
| **5**  | Not used | 值忽略 |
| **6**  | Not used | 值忽略 |
| **7**  | Not used | 值忽略 |
| **8**  | Not used | 值忽略 |
| **9**  | **Discharge current, DACIIN 0** | 0 = 增加 0 mA 的放电电流 1 = 增加 512 mA 的放电电流 |
| **10** | **Discharge current, DACIIN 1** | 0 = 增加 0 mA 的放电电流 1 = 增加 1024 mA 的放电电流  |
| **11** | **Discharge current, DACIIN 2** | 0 = 增加 0 mA 的放电电流 1 = 增加 2048 mA 的放电电流  |
| **12** | **Discharge current, DACIIN 3** | 0 = 增加 0 mA 的放电电流 1 = 增加 4096 mA 的放电电流  |
| **13** | **Discharge current, DACIIN 4** | 0 = 增加 0 mA 的放电电流 1 = 增加 8192 mA 的放电电流  |
| **14** | **Discharge current, DACIIN 5** | 0 = 增加 0 mA 的放电电流 1 = 增加 16384 mA 的放电电流 |
| **15** | Not used | 1 = 无效写入 |

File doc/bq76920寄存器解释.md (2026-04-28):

### 1. 系统状态与控制寄存器 (System Status & Control)

这些寄存器用于监控芯片状态、清除故障以及控制 MOS 管和 ADC 的开关。

| 寄存器名称  | 地址 | 位 (Bit) | 名称 | 读/写 | 复位值 | 功能详解 |
| --- | ---- | --- | --- | ----- | --- | --- |
| SYS_STAT | 0x00 | 7 | CC_READY | RW | 0 | 库仑计数器就绪。1=新的电流积分数据已准备好；0=无新数据。需写1清除。 |
| | | 6 | RSVD | - | 0 | 保留，勿用。 |
| | | 5 | DEVICE_XREADY | RW | 0 | 内部芯片故障。1=检测到内部逻辑错误（通常由瞬态干扰引起）。需写1清除。 |
| | | 4 | OVRD_ALERT | RW | 0 | ALERT 引脚外部强制。1=ALERT 引脚被外部电路拉高（如二级保护IC）。需写1清除。 |
| | | 3 | UV | RW | 0 | 欠压故障。1=检测到电池欠压。需写1清除。清除后需重新开启 DSG。 |
| | | 2 | OV | RW | 0 | 过压故障。1=检测到电池过压。需写1清除。清除后需重新开启 CHG。 |
| | | 1 | SCD | RW | 0 | 放电短路故障。1=检测到短路。需写1清除。清除后需重新开启 DSG。 |
| | | 0 | OCD | RW | 0 | 放电过流故障。1=检测到过流。需写1清除。清除后需重新开启 DSG。 |
| CELLBAL1 | 0x01 | 7-5 | RSVD | R | 0 | 保留。 |
| (均衡控制1) | | 4-0 | CB5-CB1 | RW | 0 | 电芯均衡开关。1=开启对应电芯 (Cell 1~5) 的均衡；0=关闭。 |
| SYS_CTRL1 | 0x04 | 7 | LOAD_PRESENT  | R | 0 | 负载存在检测。仅当 CHG_OFF 时有效。1=CHG 引脚被外部拉高，说明负载仍连接在 PACK- 上。 |
| (系统控制1) | | 6-5 | RSVD | R | 0 | 保留。 |
| | | 4 | ADC_EN | RW | 0 | ADC 使能。1=开启电压/温度测量（同时开启 OV/UV 保护）；0=关闭以省电。 |
| | | 3 | TEMP_SEL | RW | 0 | 温度源选择。0=读取内部芯片温度；1=读取外部热敏电阻 (TSx) 温度。 |
| | | 2 | RSVD | RW | 0 | 保留，必须写 0。 |
| | | 1-0 | SHUT_A/B | RW | 0 | 关机序列控制。进入 SHIP 模式需按特定顺序写入： 1. 写 `0x02` (A=0, B=1) 2. 写 `0x04` (A=1, B=0)。 |
| SYS_CTRL2 | 0x05 | 7 | DELAY_DIS | RW | 0 | 禁用保护延时。1= bypass OV/UV/OCD/SCD 的延时逻辑（用于产线快速测试），故障立即触发。正常使用时应为 0。 |
| (系统控制2) | | 6 | CC_EN | RW | 0 | 库仑计数器常开。1=持续进行电流积分；0=关闭常开模式。 |
| | | 5 | CC_ONESHOT | RW | 0 | 单次电流测量。1=触发一次 250ms 的电流测量，完成后自动清零。仅在 CC_EN=0 时有效。 |
| | | 4-2 | RSVD | RW | 0 | 保留，必须写 0。 |
| | | 1 | DSG_ON | RW | 0 | 放电 MOS 管控制。1=开启放电通路；0=关闭。故障发生后不会自动恢复，需软件写入 1。 |
| | | 0 | CHG_ON | RW | 0 | 充电 MOS 管控制。1=开启充电通路；0=关闭。故障发生后不会自动恢复，需软件写入 1。 |

### 2. 保护配置寄存器 (Protection Configuration)

用于设置过流、短路的阈值和延时，以及过压、欠压的阈值和延时。

| 寄存器名称 | 地址 | 位 (Bit) | 名称 | 功能详解 |
| --- | ---- | --- | --- | --- |
| PROTECT1 | 0x06 | 7 | RSNS | 量程倍增。0=低量程 (OCD/SCD 阈值较低)；1=高量程 (阈值 x2)。 配合下方阈值位使用。 |
| (短路保护1) | | 6 | RSVD | 保留。 |
| | | 5 | RSVD | 保留。 |
| | | 4-3 | SCD_DELAY  | 短路延时设置: `00`=70µs, `01`=100µs, `10`=200µs, `11`=400µs。 |
| | | 2-0 | SCD_THRESH | 短路阈值设置 (单位 mV，取决于 RSNS 位): 若 RSNS=0: `000`=22mV ... `111`=100mV 若 RSNS=1: `000`=44mV ... `111`=200mV |
| PROTECT2 | 0x07 | 7 | RSVD | 保留。 |
| (过流保护2) | | 6-4 | OCD_DELAY  | 过流延时设置: `000`=8ms ... `111`=1280ms (具体查表，呈倍数增长)。 |
| | | 3-0 | OCD_THRESH | 过流阈值设置 (单位 mV，取决于 RSNS 位): 若 RSNS=0: `0000`=8mV ... `1111`=50mV 若 RSNS=1: `0000`=17mV ... `1111`=100mV |
| PROTECT3 | 0x08 | 7-6 | UV_DELAY | 欠压延时设置: `00`=1s, `01`=4s, `10`=8s, `11`=16s。 |
| (压延保护延时) | | 5-4 | OV_DELAY | 过压延时设置: `00`=1s, `01`=2s, `10`=4s, `11`=8s。 |
| | | 3-0 | RSVD | 保留，保持默认。 |
| OV_TRIP | 0x09 | 7-0 | OV_THRESH  | 过压阈值中间8位。 实际阈值为 `10` + [这8位] + `1000` (共14位 ADC 值)。 需结合 ADCGAIN/OFFSET 计算具体电压值 (约 3.15V~4.7V)。默认 0xAC。 |
| UV_TRIP | 0x0A | 7-0 | UV_THRESH  | 欠压阈值中间8位。 实际阈值为 `01` + [这8位] + `0000` (共14位 ADC 值)。 需结合 ADCGAIN/OFFSET 计算具体电压值 (约 1.58V~3.1V)。默认 0x97。 |
| CC_CFG | 0x0B | 7-6 | RSVD | 保留。 |
| (CC 配置) | | 5-0 | CC_CFG | 必须写入 0x19 以获得最佳库仑计数器性能。 |

### 3. 数据读取寄存器 (Data Readout Registers)

这些寄存器只读，存储最新的测量数据。读取时应连续读取 HI 和 LO 字节。

| 寄存器组 | 地址范围 | 说明 |
| --- | --- | --- |
| VC1 ~ VC5 | 0x0C - 0x15 | 电芯电压 1-5。每节电芯占用 2 字节 (HI/LO)。格式为 14-bit ADC 值。 例如：VC1_HI (0x0C), VC1_LO (0x0D)。 |
| VC6 ~ VC10  | 0x16 - 0x1F | 电芯电压 6-10 (仅 BQ76930/40 有效)。 |
| VC11 ~ VC15 | 0x20 - 0x29 | 电芯电压 11-15 (仅 BQ76940 有效)。 |
| BAT | 0x2A - 0x2B | 电池组总电压。16-bit 值，LSB ≈ 1.532mV。 |
| TS1 | 0x2C - 0x2D | 温度 1。可配置为外部热敏电阻或内部芯片温度。14-bit ADC 值。  |
| TS2 | 0x2E - 0x2F | 温度 2 (仅 BQ76930/40 有效)。 |
| TS3 | 0x30 - 0x31 | 温度 3 (仅 BQ76940 有效)。 |
| CC | 0x32 - 0x33 | 库仑计数器 (电流积分)。16-bit 有符号数 (2's complement)。 电压值 = 数值 × 8.44µV。电流 = 电压 / Rsense。 |

### 4. 校准系数寄存器 (Calibration Coefficients)

这些寄存器只读，存储出厂校准的 Gain 和 Offset，用于将 ADC 原始数据转换为精确电压。

| 寄存器名称 | 地址 | 位 (Bit) | 说明 |
| --- | ---- | --- | --- |
| ADCGAIN1 | 0x50 | 4-3 | ADC Gain 高2位。 |
| ADCGAIN2 | 0x59 | 7-5 | ADC Gain 低3位。 组合成 5-bit 值，计算公式： $ Gain (\mu V/LSB) = 365 + Value $ 。范围 365~396。 |
| ADCOFFSET  | 0x51 | 7-0 | ADC Offset。8-bit 有符号数 (mV)。范围 -128mV ~ +127mV。 |

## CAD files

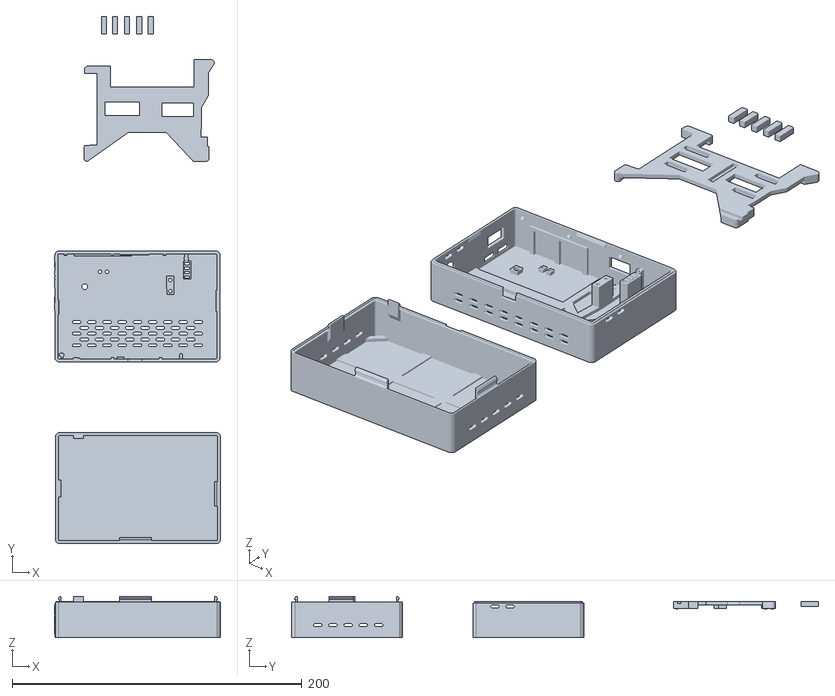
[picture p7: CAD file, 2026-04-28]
hardware/ups外壳.stl
114.7 x 363.9 x 28.4

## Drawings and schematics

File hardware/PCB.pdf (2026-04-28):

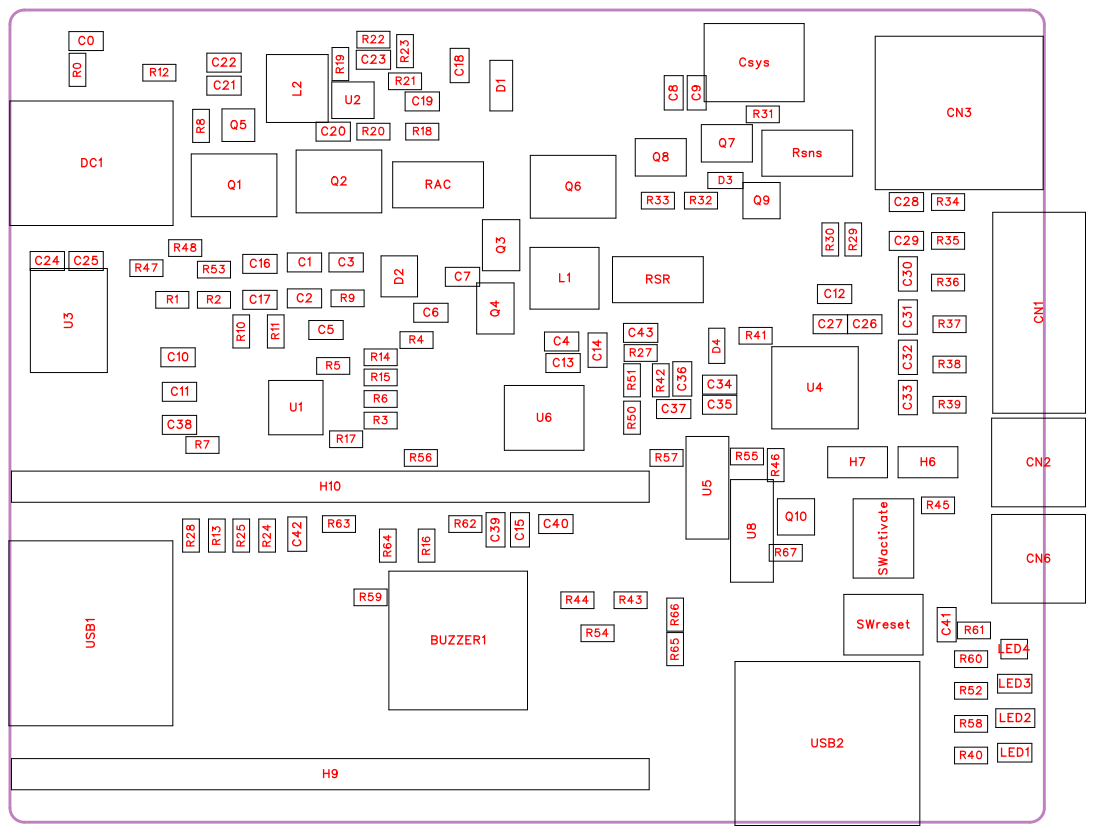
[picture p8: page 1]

C24 | C25 | R48 R47 R53 | C16 | C1 | C3 | L1 | R35 RSR

R52 | LED3

R58 | LED2

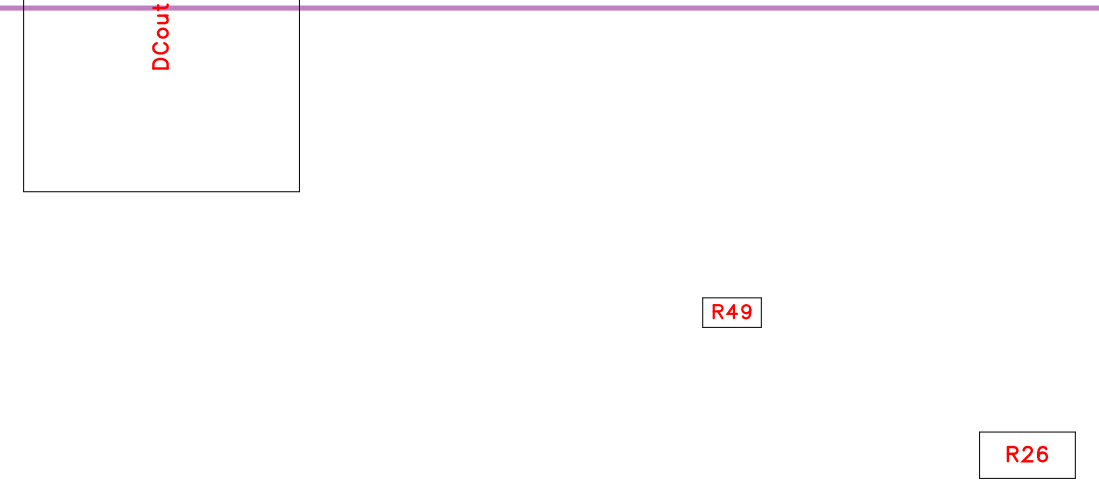
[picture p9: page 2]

Quantity | Designator | Footprint | Value | Comment | Device
1 | BUZZER1 | BUZ-TH_BD 12.0-P7.60-D 0.6-FD | 2.3kHz | 2.3kHz | TMB12A03
1 | C0 | C0603 | 2.2uF | 2.2uF | CL10A225KA 8NNNC
20 | C1,C2,C3,C4,C12,C13,C14, C18,C19,C20,C26,C27,C28 ,C29,C30,C31,C32,C33,C4 1,C43 | C0603 | 100nF | 100nF | FCC0603B10 4K500CT
5 | C5,C6,C34,C36,C37 | C0603 | 1uF | 1uF | CGA0603X5 R105K500JT
2 | C7,C16 | C0603 | 47nF | 47nF | CL10B473KB 8NNNC
4 | C8,C9,C24,C25 | C0603 | 10uF | 10uF | CGA0603X5 R106K100JT ,CL10A106M A8NRNC
5 | C10,C11,C15,C38,C40 | C0603 | 100pF | 100pF | CL10C101JB 8NNNC
1 | C17 | C0603 | 1nF | 1nF | CL10B102KB 8NNNC
2 | C21,C22 | C0603 | 22uF | 22uF | CL10A226M P8NUNE
1 | C23 | C0603 | 33pF | 33pF | CL10C330JB 8NNNC
1 | C35 | C0603 | 4.7uF | 4.7uF | CGA0603X5 R475K250JT
2 | C39,C42 | C0603 | 10nF | 10nF | CL10B103KB 8NNNC
1 | CN1 | CONN-TH_6 P-P2.50_HC ZZ0139-6 | | HX-XH2.54-6 PWZ | HX-XH2.54-6 PWZ
2 | CN2,CN6 | CONN-TH_H X-XH2.54-2P WZ | | HX-XH2.54-2 PWZ | HX-XH2.54-2 PWZ
1 | CN3 | CONN-TH_X T30PW-M | | XT30PW-M3 0.G.Y | XT30PW-M3 0.G.Y
1 | Csys | CAP-SMD_B D6.3-L6.6-W 6.6-LS7.3-FD -H7.7 | 220uF | 220uF | JVJ25V220M 6x8
1 | D1 | SOD-123FL_ L2.7-W1.8-L S3.8-RD | | SMF24A | SMF24A_C1 9077514
1 | D2 | SOT-23-3_L2 .9-W1.6-P1.9 0-LS2.8-BR | | BAT54C,215 | BAT54C,215
2 | D3,D4 | SOD-323_L1 .7-W1.3-LS2. 6-RD-1 | | BAT54WS | BAT54WS_C 7502694

1 | DC1 | DC-IN-TH_H C-DC-007B-2 .5 | | HC-DC-007B -2.5 | HC-DC-007B -2.5
1 | DCout | CONN-TH_X T30PW-F-1 | | XT30PW-F20 .G.Y | XT30PW-F20 .G.Y
2 | H6,H7 | HDR-TH_2P-P2.54-V-M | | PZ254V-11-0 2P | PZ254V-11-0 2P
2 | H9,H10 | HDR-TH_22 P-P2.54-V-F | | CS-1165SDI G-1*22 | CS-1165SDI G-1*22
1 | L1 | IND-SMD_L5 .4-W5.2_FXL 05XX | 3.3uH | 3.3uH | FXL0530-3R 3-M
1 | L2 | IND-SMD_L5 .4-W5.2_FXL 0530 | 4.7uH | 4.7uH | FXL0530-4R 7-M
1 | LED1 | LED0603-RD | | GL0603UG0 1 | GL0603UG0 1
1 | LED2 | LED0603-FD | | GL0603UR0 1 | GL0603UR0 1
1 | LED3 | LED0603-RD _BLUE | | GL0603UB01 | GL0603UB01
1 | LED4 | LED-SMD_4 P-L1.6-W0.8-RD_1 | | XL-1608SUR UGC | XL-1608SUR UGC
3 | Q1,Q2,Q6 | SOP-8_L5.0-W4.0-P1.27-LS6.0-BL | | FDS6680A | FDS6680A
4 | Q3,Q4,Q7,Q8 | PDFN-8_L3. 1-W3.1-P0.6 5-LS3.4-BL | | SIS412DN-T 1-GE3-ES | SIS412DN-T 1-GE3-ES
1 | Q5 | SC-70-3_L2. 0-W1.3-P0.6 5-LS2.1-BL | | BSS138W | BSS138W_C 890266
1 | Q9 | SOT-23-3_L2 .9-W1.3-P1.9 0-LS2.4-BR-1 | | BSS84 | BSS84_C742 0340
1 | Q10 | SOT-23-3_L2 .9-W1.3-P1.9 0-LS2.4-BR | | AO3401 | AO3401_C52 24195
1 | R0 | R0603 | 2 | 2 | 0603WAF20 0KT5E
2 | R1,R18 | R0603 | 499k | 499k | 0603WAF49 93T5E
1 | R2 | R0603 | 133k | 133k | 0603WAF13 33T5E
6 | R3,R9,R14,R15,R20,R42 | R0603 | 10 | 10 | 0603WAF10 0JT5E
1 | R4 | R0603 | 316k | 316k | 0603WAF31 63T5E

3 | R5,R44,R48 | R0603 | 100k | 100k | 0603WAF10 03T5E
5 | R6,R10,R11,R55,R67 | R0603 | 4.7k | 4.7k | 0603WAF47 01T5E
1 | R7 | R0603 | 14.3k | 14.3k | FRC0603F14 32TS
1 | R8 | R0603 | 3M | 3M | 0603WAF30 04T5E
5 | R12,R31,R32,R33,R46 | R0603 | 1M | 1M | 0603WAF10 04T5E
12 | R13,R16,R24,R25,R28,R41 ,R45,R50,R51,R62,R63,R6 4 | R0603 | 10k | 10k | FRC0603F10 02TS
1 | R17 | R0603 | 866k | 866k | FRC0603F86 63TS
1 | R19 | R0603 | 9.09k | 9.09k | FRC0603F90 91TS
1 | R21 | R0603 | 20k | 20k | 0603WAF20 02T5E
2 | R22,R56 | R0603 | 40.2k | 40.2k | FRC0603F40 22TS
1 | R23 | R0603 | 7.5k | 7.5k | 0603WAF75 01T5E
1 | R26 | R1206 | 0 | 0 | RE1206F1R0 00
3 | R27,R65,R66 | R0603 | 0 | 0 | 0603WAF00 00T5E
5 | R29,R30,R40,R52,R61 | R0603 | 100 | 100 | 0603WAF10 00T5E
9 | R34,R35,R36,R37,R38,R39 ,R53,R54,R57 | R0603 | 1k | 1k | 0603WAF10 01T5E
2 | R43,R47 | R0603 | 910k | 910k | FRC0603F91 03TS
1 | R49 | R0603 | | HNTC0603-1 03F3450FA | HNTC0603-1 03F3450FA
2 | R58,R60 | R0603 | 330 | 330 | 0603WAF33 00T5E
1 | R59 | R0603 | 47 | 47 | 0603WAF47 0JT5E
2 | RAC,RSR | R2512 | 10m | 10m | RE2512F3R0 10
1 | Rsns | R2512 | 5m | 5m | JER2512F3R 005
2 | SWactivate,SWreset | SW-SMD_4P -L5.1-W5.1-P 3.70-LS6.5-T L_H1.5 | | TS-1187A-B-A-B | TS-1187A-B-A-B
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

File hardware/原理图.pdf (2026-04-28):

## NMOS

## NMOS

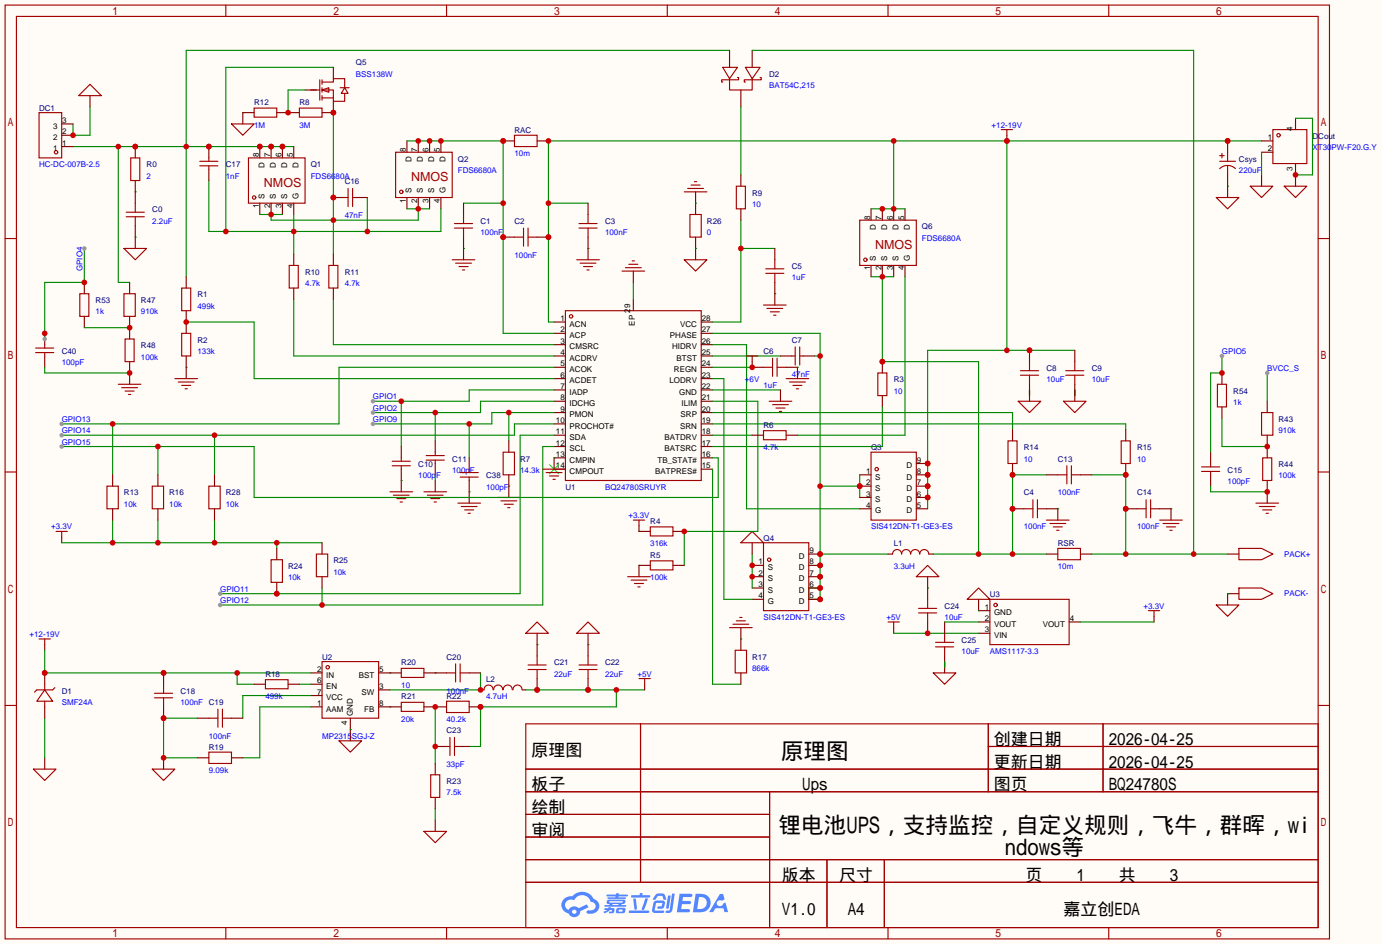
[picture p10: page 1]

原理图 | 原理图 | 创建日期 | 2026-04-25

更新日期 | 2026-04-25

板子 | Ups | 图页 | BQ24780S
绘制 | | 锂电池UPS，支持监控，自定义规则，飞牛，群晖，wi ndows等
审阅

V1.0 | A4 | 嘉立创EDA

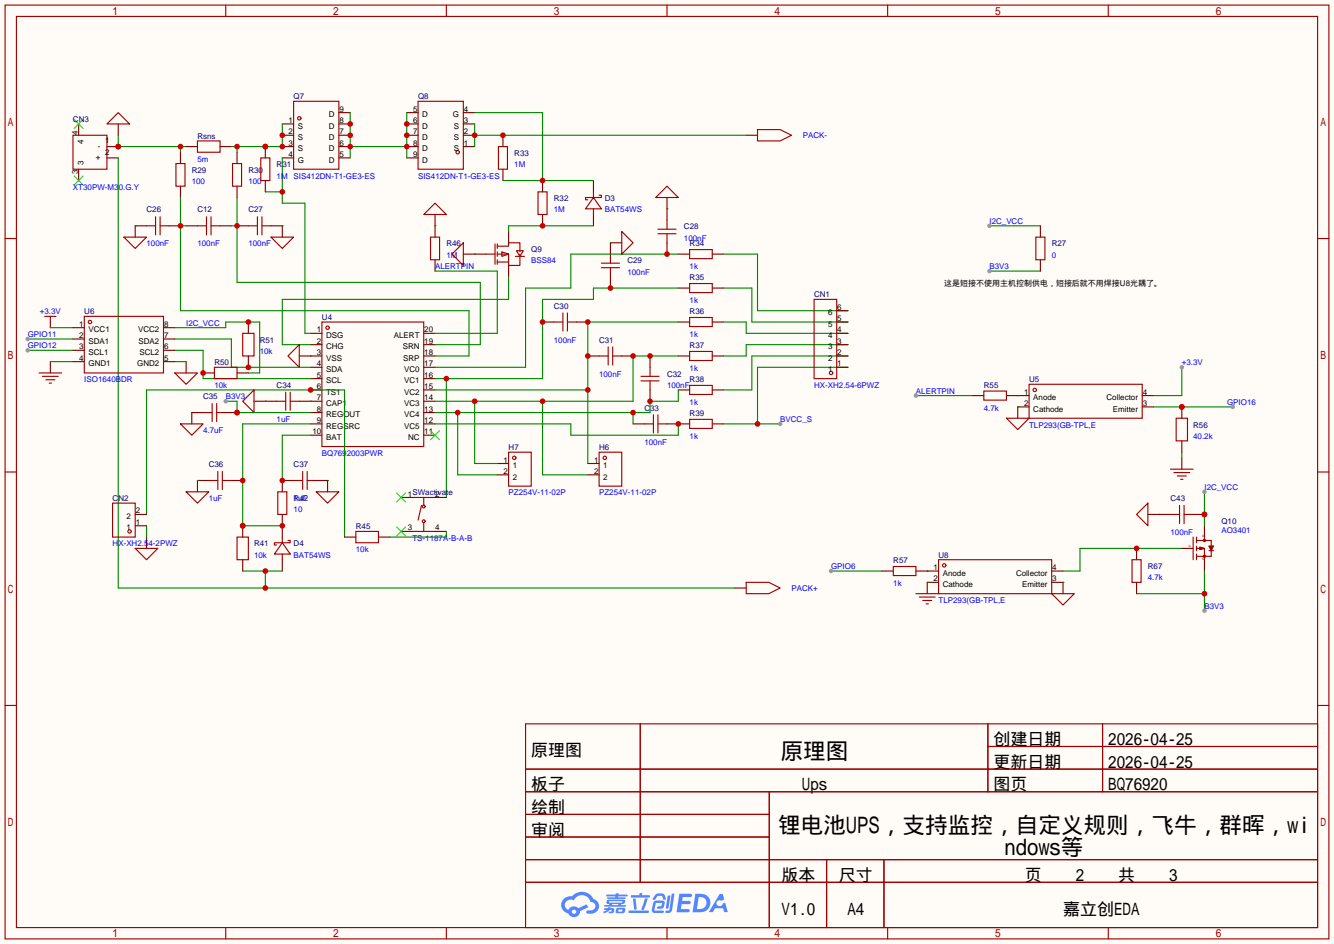
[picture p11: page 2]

原理图 | 原理图 | 创建日期 | 2026-04-25

更新日期 | 2026-04-25

板子 | Ups | 图页 | BQ76920
绘制 | | 锂电池UPS，支持监控，自定义规则，飞牛，群晖，wi ndows等
审阅

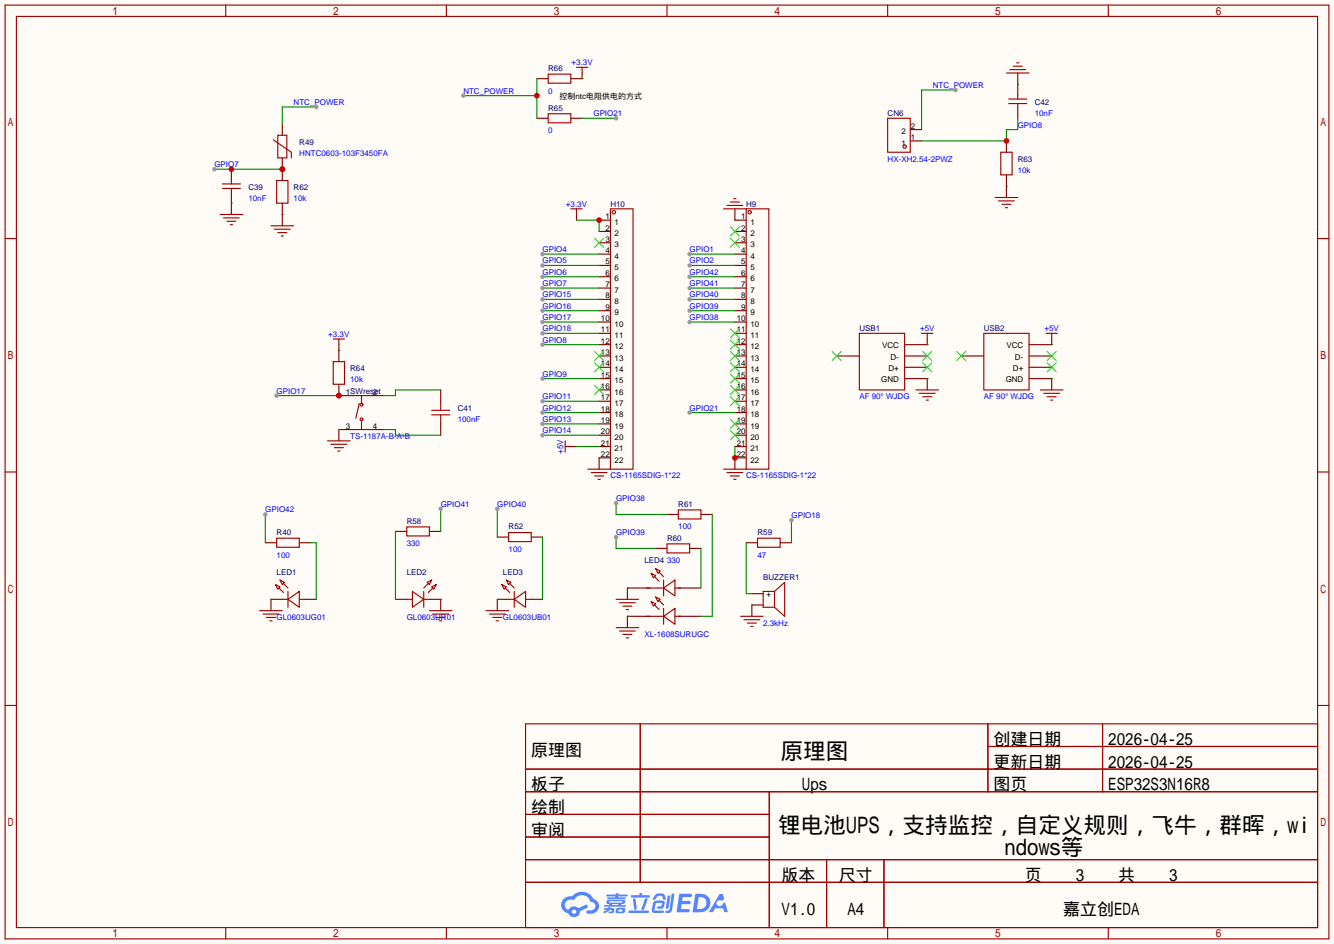
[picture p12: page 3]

原理图 | 原理图 | 创建日期 | 2026-04-25

更新日期 | 2026-04-25

板子 | Ups | 图页 | ESP32S3N16R8
绘制 | | 锂电池UPS，支持监控，自定义规则，飞牛，群晖，wi ndows等
审阅

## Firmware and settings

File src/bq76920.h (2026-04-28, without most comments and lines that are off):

#define BQ76920_H
#include <stdint.h>
#include "i2c_interface.h"
#define BQ76920_ADDRESS         0x08    ///< BQ76920 I2C地址
#define MAX_CELL_COUNT          5       ///< 最大电池单元数
#define DEFAULT_GAIN_MV_PER_LSB 0.380f  ///< 默认增益值 (mV/LSB)
#define DEFAULT_OFFSET_MV       0       ///< [修正] 默认偏移值 (mV)，原为99，现改为0以避免误差
#define RSENSE_VALUE           0.005f  // 检测电阻阻值5m
#define STATUS_REG_ADDR         0x00    ///< 状态寄存器
#define CELL_BALANCE_REG_ADDR   0x01    ///< 电池均衡寄存器
#define SYS_CTRL1_REG_ADDR      0x04    ///< 系统控制寄存器1
#define SYS_CTRL2_REG_ADDR      0x05    ///< 系统控制寄存器2
#define PROTECT1_REG_ADDR       0x06    ///< 短路保护寄存器1
#define PROTECT2_REG_ADDR       0x07    ///< 过流保护寄存器2
#define PROTECT3_REG_ADDR       0x08    ///< 压延保护延时
#define OV_TRIP_REG_ADDR        0x09    ///< 过压值寄存器
#define UV_TRIP_REG_ADDR        0x0A    ///< 欠压值寄存器
#define STAT_CC_READY       (1 << 7)
#define STAT_DEVICE_XREADY  (1 << 5)
#define STAT_OVRD_ALERT     (1 << 4) ///< 外部二级保护触发
#define STAT_UV             (1 << 3)
#define STAT_OV             (1 << 2)
#define STAT_SCD            (1 << 1)
#define STAT_OCD            (1 << 0)
#define ADC_ENABLE_BIT          0x10    ///< ADC使能位 SYS_CTRL1 bit4
#define TEMP_SELECT_BIT         0x08    ///< 温度选择位 SYS_CTRL1 bit3
#define CC_ENABLE_BIT           0x40    ///< 库仑计使能位 SYS_CTRL2 bit6
#define CHARGE_ENABLE_BIT       0x01    ///< 充电使能位 SYS_CTRL2 bit0
#define DISCHARGE_ENABLE_BIT    0x02    ///< 放电使能位 SYS_CTRL2 bit1
#define LOAD_PRESENT_BIT        0x04    ///< 负载检测位 SYS_CTRL1 bit2
#define VOLTAGE_BASE_ADDR       0x0C    ///< 电压寄存器基地址
#define VOLTAGE_REG_STEP        2       ///< 电压寄存器步长
#define VOLTAGE_HIGH_MASK       0x3F    ///< 电压高位掩码
#define VOLTAGE_ALL_ADDR        0x2A    ///< 所有电压寄存器地址高位 16bit
#define CURRENT_REG_HIGH        0x32    ///< 电流高字节寄存器
#define CURRENT_REG_LOW         0x33    ///< 电流低字节寄存器
#define CURRENT_ZERO_DRIFT      1     ///< 电流零漂值 (默认值，建议校准后覆盖)
#define CURRENT_SCALE_FACTOR    (8.44f / 5.0f)  ///< 电流缩放因子 //与检测电阻RSENSE_VALUE相关
#define TEMP_REG_HIGH           0x2C    ///< 温度高字节寄存器
#define TEMP_REG_LOW            0x2D    ///< 温度低字节寄存器
#define TEMP_HIGH_MASK          0x3F    ///< 温度高位掩码
#define CC_CFG_REG_ADDR         0x0B    ///< CC配置寄存器
#define GAIN_REG1_ADDR          0x50    ///< 增益寄存器1
#define GAIN_REG2_ADDR          0x59    ///< 增益寄存器2
#define OFFSET_REG_ADDR         0x51    ///< 偏移寄存器
#define BASE_GAIN_UV            365     ///< 基础增益值 (uV)
#define GAIN_MASK1              0x0C    ///< 增益掩码1
#define GAIN_MASK2              0xE0    ///< 增益掩码2
#define GAIN_SHIFT1             1       ///< 增益左移位数
#define GAIN_SHIFT2             5       ///< 增益右移位数
#define UV_TO_MV_FACTOR         1000.0f ///< uV转mV因子
#define TEMP_TABLE_START        -10     ///< 表格起始温度
#define TEMP_TABLE_END          95      ///< 表格结束温度
#define TEMP_TABLE_SIZE         106     ///< 表格元素个数
const uint16_t TEMP_LOOKUP_TABLE[] = {
    7373, 7310, 7246, 7179, 7110, 7040, 6967, 6893, 6816, 6738, // -10 ~ -1°C
    6658, 6577, 6493, 6408, 6322, 6234, 6145, 6054, 5962, 5870, // 0 ~ 9°C
    5776, 5681, 5586, 5489, 5393, 5295, 5198, 5100, 5002, 4903, // 10 ~ 19°C
    4805, 4707, 4610, 4512, 4416, 4319, 4224, 4129, 4035, 3942, // 20 ~ 29°C
    3849, 3758, 3668, 3579, 3491, 3405, 3320, 3236, 3154, 3073, // 30 ~ 39°C
    2993, 2915, 2838, 2763, 2690, 2618, 2548, 2479, 2411, 2345, // 40 ~ 49°C
    2281, 2218, 2157, 2098, 2039, 1983, 1927, 1873, 1821, 1770, // 50 ~ 59°C
    1720, 1672, 1625, 1579, 1534, 1491, 1449, 1408, 1369, 1330, // 60 ~ 69°C
    1293, 1256, 1221, 1187, 1154, 1121, 1090, 1060, 1030, 1001, // 70 ~ 79°C
    974, 947, 921, 895, 871, 847, 824, 801, 779, 758, // 80 ~ 89°C
    738, 718, 698, 680, 662, 644, // 90 ~ 95°C
};
#define INVALID_TEMPERATURE     -99.0f  ///< 无效温度值
#define INIT_RETRY_COUNT        5       ///< 初始化重试次数
#define INIT_DELAY_MS           10      ///< 初始化延时(ms)
#define ADC_STABILIZE_DELAY_MS  100    ///< ADC稳定延时(ms)
#define CALIBRATION_RETRY_DELAY_MS 100  ///< 校准重试延时(ms)
#define CALIBRATION_MIN_GAIN    0.30f   ///< 最小增益阈值
#define CALIBRATION_OFFSET_MIN  -50     ///< 偏移最小值
#define CALIBRATION_OFFSET_MAX  50      ///< 偏移最大值
#define CALIBRATION_GAIN_MIN    0.35f   ///< 增益最小值
#define CALIBRATION_GAIN_MAX    0.40f   ///< 增益最大值
#define DEFAULT_CALIBRATION_GAIN 0.381f ///< 默认校准增益
#define GAIN_ADJUSTMENT_FACTOR  1.0f ///< 增益调整因子
typedef enum {
    TEMP_SOURCE_INTERNAL = 0, // 内部 Die 温度
    TEMP_SOURCE_EXTERNAL = 1  // 外部热敏电阻 (TS1)
} BMS_TempSource_t;
typedef enum {
    OCD_DELAY_8_MS    = 0,
    OCD_DELAY_20_MS   = 1,
    OCD_DELAY_40_MS   = 2,
    OCD_DELAY_80_MS   = 3,
    OCD_DELAY_160_MS  = 4,
    OCD_DELAY_320_MS  = 5,
    OCD_DELAY_640_MS  = 6,
    OCD_DELAY_1280_MS = 7
} BMS_OCDDelay_t;
typedef enum {
    SCD_DELAY_70_US  = 0,
    SCD_DELAY_100_US = 1,
    SCD_DELAY_200_US = 2,
    SCD_DELAY_400_US = 3
} BMS_SCDDelay_t;
typedef enum {
    OV_DELAY_1_S  = 0,
    OV_DELAY_2_S  = 1,
    OV_DELAY_4_S  = 2,
    OV_DELAY_8_S  = 3
} BMS_OVDelay_t;
typedef enum {
    UV_DELAY_1_S  = 0,
    UV_DELAY_4_S  = 1,
    UV_DELAY_8_S  = 2,
    UV_DELAY_16_S = 3
} BMS_UVDelay_t;
static constexpr float BQ76920_OCD_THRESH_HIGH[] = {17, 22, 28, 33, 39, 44, 50, 56, 61, 67, 72, 78, 83, 89, 94, 100};
static constexpr float BQ76920_OCD_THRESH_LOW[]  = {8, 11, 14, 17, 19, 22, 25, 28, 31, 33, 36, 39, 42, 44, 47, 50};
static constexpr float BQ76920_SCD_THRESH_HIGH[] = {44, 67, 89, 111, 133, 155, 178, 200};
static constexpr float BQ76920_SCD_THRESH_LOW[]  = {22, 33, 44, 56, 67, 78, 89, 100};
static constexpr uint16_t BQ76920_OCD_DELAY_MS[] = {8, 20, 40, 80, 160, 320, 640, 1280};
static constexpr uint16_t BQ76920_SCD_DELAY_US[] = {70, 100, 200, 400};
struct BQ76920Data {
    uint16_t cell_voltage[MAX_CELL_COUNT];
    int16_t current;
    float temperature;
    float gain;
    int8_t offset;
    bool chg_enabled;
    bool dsg_enabled;
    unsigned long last_update;
    uint8_t actual_cell_count;
};
struct BQ76920_InitConfig {
    uint8_t cell_count;                   // 电池串数 (3-5)
    uint16_t cell_ov_threshold;           // 单节过压阈值 (mV)
    uint16_t cell_uv_threshold;           // 单节欠压阈值 (mV)
    BMS_OVDelay_t ov_delay;               // 过压延时
    BMS_UVDelay_t uv_delay;               // 欠压延时
    int16_t max_discharge_current;        // 最大放电电流 (mA)
    BMS_OCDDelay_t ocd_delay;             // 过流延时
    int16_t short_circuit_threshold;      // 短路阈值 (mA)
    BMS_SCDDelay_t scd_delay;             // 短路延时
    bool coulomb_counter_enabled;         // 是否启用库仑计
};
class BQ76920 {
public:
    BQ76920();
    explicit BQ76920(I2CInterface& i2c_interface);
    bool begin();
    bool initializeChip(const BQ76920_InitConfig &config);
    bool updateConfiguration(const BQ76920_InitConfig &config);
    bool setOVThreshold(uint16_t voltage_mV);
    bool setUVThreshold(uint16_t voltage_mV);
    float getOVThreshold();
    float getUVThreshold();
    bool setOVUVDelay(BMS_OVDelay_t ovDelay, BMS_UVDelay_t uvDelay);
    bool getOCDProtection(float* threshold_mV, uint16_t* delay_ms);
    bool getSCDProtection(float* threshold_mV, uint16_t* delay_us);
    uint8_t getFaultStatus();
    bool clearFaults(uint8_t mask);
    bool setCellBalance(uint8_t cellMask);
    bool isLoadPresent();
    bool enterShipMode();
    void calibrateCurrentZero();
    void setCurrentZeroDrift(int16_t drift); // 允许手动设置零漂
    bool readRegister(uint8_t reg, uint8_t *value);
    bool readRegisterWord(uint8_t reg, uint16_t *value);
    bool writeRegister(uint8_t reg, uint8_t value);
    uint8_t getDeviceAddress() const { return BQ76920_ADDRESS; }
    bool isConnected();
    void readADCParams();
    uint16_t getCellVoltage_mV(uint8_t cell_idx);
    bool getCellVoltages_mV(uint16_t* voltages, uint8_t count);
    uint8_t getBalanceMaskForCell(uint8_t cell_idx);
    uint8_t getActualCellCount() const { return actual_cell_count; }
    void setMOS(uint8_t chg, uint8_t dsg);
    bool getMOS(bool& isCHG, bool& isDSG);
    int16_t getCurrent_mA();
    float getTempCelsius();
    uint16_t getTotalVoltage_mV();
    float getBqGain() const { return bq_gain; }
    int8_t getBqOffset() const { return bq_offset; }
    bool isCoulombCounterReady();
    bool clearCoulombCounterFlag();
    bool readCoulombCounterRaw(int16_t &rawValue);
    void printRegisters();
    bool readAllRegisters(uint8_t* values);
private:
    I2CInterface* i2c;      ///< I2C 接口指针
    float bq_gain;          ///< ADC 增益值 (mV/LSB)
    int8_t bq_offset;       ///< ADC 偏移值 (mV)
    int16_t current_zero_drift; ///< 动态电流零漂值
    uint8_t actual_cell_count;  ///< 实际电池串数
    bool last_connection_status_ = false;           ///< 上次连接检测结果
    unsigned long last_connection_check_time_ = 0;  ///< 上次连接检测时间戳
    uint8_t calculateTripReg(uint16_t voltage_mV, float gain, float offset);
    uint8_t findClosestOCDThreshold(float target_mV, bool &rsnsBit);
    uint8_t findClosestSCDThreshold(float target_mV, bool &rsnsBit);
    bool setOCDProtection(float threshold_mV, BMS_OCDDelay_t delay);
    bool setSCDProtection(float threshold_mV, BMS_SCDDelay_t delay);
};

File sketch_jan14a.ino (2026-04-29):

/*
 * UPS Control System for ESP32 with BQ24780S and BQ76920
 */

#include <ESPAsyncWebServer.h>
#include <ArduinoJson.h>
#include <time.h>
#include <esp_task_wdt.h>

#include "src/data_structures.h"
#include "src/pins_config.h"
#include "src/config_manager.h"
#include "src/hardware_interface.h"
#include "src/web_server.h"
#include "src/i2c_interface.h"
#include "src/bq24780s.h"
#include "src/bq76920.h"
#include "src/bms.h"
#include "src/power_management.h"
#include "src/system_management.h"
#include "src/WiFiManager.h"
#include "src/time_utils.h"
#include "src/ups_hid_service.h"
#include "src/mqtt_service.h"

// =============================================================================
// OTA 固件特征标签
// 格式: "SIG:<PROJECT_NAME>:VER:<VERSION>"
// =============================================================================
char FIRMWARE_ID_TAG[50];

// =============================================================================
// Global Objects
// =============================================================================

ConfigManager configManager;
HardwareInterface* hardware = nullptr;
BMS* bms = nullptr;
PowerManagement* powerManagement = nullptr;
SystemManagement* systemManager = nullptr;
WebServer* webServer = nullptr;
WiFiManager* wifiManager = nullptr;

System_Global_State globalSystemState;
Configuration* systemConfig = nullptr;
BMS_Config_t* bmsConfig = nullptr;
Power_Config_t* powerConfig = nullptr;

bool g_force_factory_reset = false;
UPS_HID_Service* upsHidService = nullptr;
MQTTService* mqttService = nullptr;

// =============================================================================
// Helper Functions
// =============================================================================

bool checkFactoryReset() {
  pinMode(RESET_BUTTON_PIN, INPUT_PULLUP);
  char version[] = "SIG:OPENUPS-ESP32S3:VER:1.0.9";
  strcpy(FIRMWARE_ID_TAG, version);
  Serial.println(F("Checking for factory reset button..."));
  
  const unsigned long detectionTimeout = 3000;
  const unsigned long minPressDuration = 2500;
  unsigned long startTime = millis();
  unsigned long pressStartTime = 0;
  bool buttonPressed = false;
  
  while (millis() - startTime < detectionTimeout) {
    if (digitalRead(RESET_BUTTON_PIN) == LOW) {
      if (!buttonPressed) {
        pressStartTime = millis();
        buttonPressed = true;
        Serial.println(F("Reset button pressed, timing..."));
      }
      if (millis() - pressStartTime >= minPressDuration) {
        Serial.println(F("Factory Reset Triggered!"));
        return true;
      }
    } else if (buttonPressed) {
      Serial.println(F("Button released too early (< 2.5s)"));
      buttonPressed = false;
    }
    delay(1);
  }
  
  Serial.println(F("Normal Boot"));
  return false;
}

template<typename T>
bool initModule(T*& module, const char* name) {
  unsigned long startTime = millis();
  Serial.printf_P(PSTR("%s::begin() started\n"), name);
  
  if (!module->begin()) {
    Serial.printf_P(PSTR("%s::begin() failed after %lu ms\n"), name, millis() - startTime);
    return false;
  }
  
  Serial.printf_P(PSTR("%s::begin() completed in %lu ms\n"), name, millis() - startTime);
  return true;
}

// =============================================================================
// System Initialization
// =============================================================================

bool initializeSystemModules() {
  Serial.println(F("=== Starting System Module Initialization ==="));
  
  // Step 1: ConfigManager
  Serial.println(F("Step 1: Initializing ConfigManager..."));
  configManager.begin();
  bool needsConfig = configManager.loadConfiguration(g_force_factory_reset);
  Serial.println(needsConfig ? F("ConfigManager: CONFIG MODE") : F("ConfigManager: NORMAL MODE"));
  delay(1);
  
  systemConfig = configManager.getSystemConfig();
  bmsConfig = configManager.getBMSConfig();
  powerConfig = configManager.getPowerConfig();
  
  if (!systemConfig || !bmsConfig || !powerConfig) {
    Serial.println(F("ERROR: Failed to get configuration pointers"));
    return false;
  }
  
  // Step 2: HardwareInterface
  Serial.println(F("Step 2: Initializing HardwareInterface..."));
  hardware = new HardwareInterface(*systemConfig);
  if (!initModule(hardware, "HardwareInterface")) {
    delete hardware;
    hardware = nullptr;
    return false;
  }
  if (g_force_factory_reset) {
    hardware->setBuzzer(BUZZER_MODE_BEEP_ONCE);
  }
  
  delay(1);
  
  // Config mode: skip heavy modules
  if (needsConfig) {
    Serial.println(F("=== CONFIG MODE: Skipping BMS/Power/System modules ==="));
    bms = nullptr;
    powerManagement = nullptr;
    systemManager = nullptr;
    
    Serial.println(F("Step 6: Initializing WebServer (CONFIG MODE)..."));
    webServer = new WebServer(&configManager, nullptr, 80);
    
    Serial.println(F("Step 7: Initializing WiFiManager..."));
    wifiManager = new WiFiManager(hardware);
    delay(1);
    
    hardware->setLED(POWER_LED_PIN, LED_MODE_BLINK_SLOW);
    hardware->setRGBLED(RGB_MODE_BREATHING, {0, 0, 255});
    Serial.println(F("=== CONFIG MODE Initialization Complete ==="));
    return true;
  }
  
  // Normal mode: full initialization
  // Step 3: BMS
  Serial.println(F("Step 3: Initializing BMS..."));
  bms = new BMS(hardware->getI2CInterface(), *bmsConfig);
  
  if (!initModule(bms, "BMS")) {
    Serial.println(F("WARNING: BMS not found, running in limited mode"));
    delete bms;
    bms = nullptr;
  }
  
  delay(1);
  
  // Step 4: PowerManagement
  Serial.println(F("Step 4: Initializing PowerManagement..."));
  Serial.printf_P(PSTR("PowerManagement: BMS pointer is %s\n"), bms ? "valid" : "nullptr");
  powerManagement = new PowerManagement(*powerConfig, *hardware);
  if (!initModule(powerManagement, "PowerManagement")) {
    Serial.println(F("WARNING: PowerManagement not found, running without charging control"));
    delete powerManagement;
    powerManagement = nullptr;
  }
  delay(1);
  
  // Step 5: UPS HID Service (conditional based on config)
  Serial.println(F("Step 5: Initializing UPS HID Service..."));
  if (systemConfig->hid_enabled) {
    upsHidService = new UPS_HID_Service();
    upsHidService->setDeviceIdentifier(systemConfig->identifier);
    upsHidService->setCapacityMode(systemConfig->hid_report_mode);
    upsHidService->setBatteryConfig(bmsConfig->cell_count, 3700, bmsConfig->nominal_capacity_mAh);
    //暂不启动，等待系统启动稳定后启动
  } else {
    Serial.println(F("UPS HID Service disabled in configuration"));
    upsHidService = nullptr;
  }
  delay(1);
  
  // Step 6: SystemManagement
  Serial.println(F("Step 6: Initializing SystemManagement..."));
  // MQTT Service initialization (conditional based on config)
  if (systemConfig->mqtt_broker[0] != 0 && systemConfig->mqtt_port > 0) {
    mqttService = new MQTTService();
  }
  
  // SystemManagement with optional MQTT service
  systemManager = new SystemManagement(*hardware, bms, powerManagement, configManager, upsHidService, mqttService);
  if (!systemManager->initialize()) {
    Serial.println(F("ERROR: Failed to initialize SystemManagement"));
    delete systemManager;
    systemManager = nullptr;
    return false;
  }
  Serial.println(F("SystemManagement initialized successfully"));
  delay(1);
  
  // Step 7: WebServer
  Serial.println(F("Step 7: Initializing WebServer..."));
  webServer = new WebServer(&configManager, systemManager, 80);
  delay(1);
  
  // Step 8: WiFiManager
  Serial.println(F("Step 8: Initializing WiFiManager..."));
  wifiManager = new WiFiManager(hardware);
  delay(1);
  
  Serial.println(F("=== All System Modules Initialized Successfully ==="));
  return true;
}

// =============================================================================
// Arduino Setup
// =============================================================================

void setup() {
  Serial.begin(115200);

  g_force_factory_reset = checkFactoryReset();
  
  Serial.println(F("=== UPS Control System Starting ==="));
  Serial.printf_P(PSTR("Build: %s %s\n"), __DATE__, __TIME__);
  
  if (!initializeSystemModules()) {
    Serial.println(F("FATAL Error: System initialization failed"));
    Serial.println(F("System will restart automatically..."));
    delay(100);
    while (1) delay(1000);
  }
  
  // WiFi setup - 统一使用begin()处理所有情况
  Serial.println(F("Initializing WiFi Manager..."));
  wifiManager->begin(systemConfig);
  
  Serial.println(F("Starting WebServer..."));
  webServer->begin();
  
  initTimeSystem(28800, systemConfig->ntp_server); 
  
  Serial.println(F("=== System Setup Complete ==="));
}

// =============================================================================
// Arduino Loop
// =============================================================================

void loop() {
  if (wifiManager) wifiManager->loop();
  updateTimeSystem();
  
  // Config mode: only basic services, reduced frequency to save power
  if (!systemManager) {
    hardware->update();
    delay(500);  // 降低循环频率，减少芯片发热
    return;
  }
  
  if (!systemManager->isSystemReady()) {
    delay(100);
    return;
  }
  
  systemManager->update();
  
  // Web notification (1s interval)
  static unsigned long lastWebNotify = 0;
  if (millis() - lastWebNotify > 3000) {
    webServer->notifyClients();
    lastWebNotify = millis();
  }
  
  delay(10);
}

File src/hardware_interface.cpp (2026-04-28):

#include "hardware_interface.h"
#include "utils.h"
#include <Arduino.h>
#include <FastLED.h>
#include <math.h>

static HardwareInterface* g_hardware_instance = nullptr;

HardwareInterface::HardwareInterface(uint8_t led_brightness, uint8_t buzzer_volume, bool buzzer_enabled)
    : i2cInterface_(), system_status_(0), last_update_time_(0), last_led_update_time_(0),
      button_press_start_time_(0), flag_acok_changed_(false), flag_prochot_alert_(false),
      flag_tbstat_changed_(false), flag_bms_alert_(false), flag_button_pressed_(false),
      button_state_(BTN_IDLE), last_acok_state_(false), last_prochot_state_(false),
      last_tbstat_state_(false), rgb_mode_(RGB_MODE_OFF), rgb_color_{0, 0, 0},
      buzzer_mode_(BUZZER_MODE_BEEP_ONCE) {
    
    led_brightness_ = Utils::applyGammaMapping(min(led_brightness, (uint8_t)100), 80);
    buzzer_volume_ = Utils::applyGammaMapping(min(buzzer_volume, (uint8_t)100), 150);
    buzzer_enabled_ = buzzer_enabled;
    
    memset(led_modes_, LED_MODE_OFF, sizeof(led_modes_));
    
    // Initialize ADC calibration coefficients to default (100 = 1.00x)
    memset(adc_calibration_, ADC_CAL_DEFAULT_VALUE, sizeof(adc_calibration_));
    
    // Initialize Preferences for ADC calibration storage
    adc_cal_preferences_.begin(ADC_CAL_NVS_NAMESPACE, false);
    
    g_hardware_instance = this;
    
    Serial.printf_P(PSTR("HW: brightness=%u%%->%u, volume=%u%%->%u, enabled=%s\n"),
                   min(led_brightness, (uint8_t)100), led_brightness_,
                   min(buzzer_volume, (uint8_t)100), buzzer_volume_,
                   buzzer_enabled_ ? "yes" : "no");
}

HardwareInterface::HardwareInterface(const Configuration& config)
    : HardwareInterface(config.led_brightness, config.buzzer_volume, config.buzzer_enabled) {}

bool HardwareInterface::begin() {
    Serial.println(F("HW: Initializing..."));
    
    initGPIOs();

    if (!i2cInterface_.initialize(I2C_SDA_PIN, I2C_SCL_PIN, 100000)) {
        Serial.println(F("HW: I2C init failed"));
        return false;
    }

    //i2cInterface_.scanI2CBus();
    
    attachInterrupt(digitalPinToInterrupt(BQ24780S_ACOK_PIN), handleAcokInterrupt, CHANGE);
    attachInterrupt(digitalPinToInterrupt(BQ24780S_PROCHOT_PIN), handleProchotInterrupt, CHANGE);
    attachInterrupt(digitalPinToInterrupt(BQ24780S_TBSTAT_PIN), handleTbstatInterrupt, CHANGE);
    attachInterrupt(digitalPinToInterrupt(BQ76920_ALERT_PIN), handleBmsAlertInterrupt, RISING); 
    attachInterrupt(digitalPinToInterrupt(RESET_BUTTON_PIN), handleButtonInterrupt, FALLING);
    
    // Initialize ADC calibration from Preferences
    initADCCalibration();
    
    Serial.println(F("HW: Init complete"));
    return true;
}

void HardwareInterface::initADCCalibration() {
    Serial.println(F("HW: Loading ADC calibration from Preferences..."));
    bool any_loaded = false;
    
    for (uint8_t i = 0; i < ADC_CAL_PIN_COUNT; i++) {
        char key[16];
        snprintf(key, sizeof(key), "pin_%u", ADC_CAL_PINS[i]);
        
        uint32_t cal_value = adc_cal_preferences_.getUInt(key, ADC_CAL_DEFAULT_VALUE);
        if (cal_value >= ADC_CAL_MIN_VALUE && cal_value <= ADC_CAL_MAX_VALUE) {
            adc_calibration_[i] = (uint8_t)cal_value;
            any_loaded = true;
            Serial.printf_P(PSTR("HW: ADC cal pin %u -> %u (%.2fx)\n"),
                           ADC_CAL_PINS[i], adc_calibration_[i], adc_calibration_[i] / 100.0f);
        }
    }
    
    if (any_loaded) {
        Serial.println(F("HW: ADC calibration loaded from Preferences"));
    } else {
        Serial.println(F("HW: No valid ADC calibration found, using defaults"));
    }
}

void HardwareInterface::initGPIOs() {
    // Input pins
    pinMode(BQ24780S_ACOK_PIN, INPUT);      
    pinMode(BQ24780S_PROCHOT_PIN, INPUT);   
    pinMode(BQ24780S_TBSTAT_PIN, INPUT); 
    pinMode(BQ76920_ALERT_PIN, INPUT); 
    
    // Output pins
    const uint8_t output_pins[] = {
        BQ76920_I2CVCC_PIN, POWER_LED_PIN, CHARGING_LED_PIN, DISCHARGING_LED_PIN,
        WIFI_FAIL_LED_PIN, WIFI_SUCCESS_LED_PIN, BUZZER_PIN, RGB_LED_PIN,
        TEMP_POWER_PIN
    };
    
    for (uint8_t pin : output_pins) {
        pinMode(pin, OUTPUT);
        digitalWrite(pin, LOW);
    }

    FastLED.addLeds<WS2812, RGB_LED_PIN, GRB>(leds_, 1);
    FastLED.setBrightness(led_brightness_); 
    
    analogSetAttenuation(ADC_11db); 
    analogReadResolution(12);
    
    Serial.println(F("HW: GPIOs configured"));
}
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

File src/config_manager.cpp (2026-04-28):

#include "config_manager.h"
#include "Arduino.h"
#include "pins_config.h"
#include "event_bus.h"
#include "event_types.h"

// 静态实例指针，供事件回调使用
static ConfigManager* s_configManagerInstance = nullptr;

ConfigManager::ConfigManager() : m_isConfigModeRequired(false) {
    loadDefaults();
}

void ConfigManager::begin() {
    s_configManagerInstance = this;
    EventBus::getInstance().subscribe(EVT_CONFIG_SYSTEM_CHANGE_REQUEST, onConfigChangeRequest);
}

bool ConfigManager::loadConfiguration(bool forceReset) {
    Serial.println(F("Loading configuration from flash..."));
    
    // 1. 优先判断：如果强制重置，直接恢复默认值并进入配置模式
    if (forceReset) {
        Serial.println(F("Force reset requested - resetting to defaults"));
        resetToDefaults();
        m_isConfigModeRequired = true;
        
        // 保存默认配置到 Flash
        writeToFlash();
        return true;
    }
    
    // 2. 尝试从 NVS 读取配置
    preferences.begin("ups_config", true); // ReadOnly mode
    
    // Load all configurations together
    Configuration loadedSystemConfig;
    BMS_Config_t loadedBMSConfig;
    Power_Config_t loadedPowerConfig;
    
    size_t systemBytes = preferences.getBytes("sys_config", &loadedSystemConfig, sizeof(Configuration));
    size_t bmsBytes = preferences.getBytes("bms_config", &loadedBMSConfig, sizeof(BMS_Config_t));
    size_t powerBytes = preferences.getBytes("power_config", &loadedPowerConfig, sizeof(Power_Config_t));
    
    preferences.end();
    
    // 3. 检查读取是否成功
    bool systemValid = (systemBytes == sizeof(Configuration)) && validateSystemConfig(loadedSystemConfig);
    bool bmsValid = (bmsBytes == sizeof(BMS_Config_t)) && validateBMSConfig(loadedBMSConfig);
    bool powerValid = (powerBytes == sizeof(Power_Config_t)) && validatePowerConfig(loadedPowerConfig);

    // 4. 核心业务完整性判断
    bool allValid = systemValid && bmsValid && powerValid;
    
    if (!allValid) {
        Serial.println(F("Configuration read failed or invalid - entering config mode"));
        
        // 打印详细错误信息
        if (!systemValid) {
            if (systemBytes > 0) {
                Serial.println(F("  - System configuration invalid or incomplete"));
            } else {
                Serial.println(F("  - System configuration not found"));
            }
        }
        if (!bmsValid) {
            if (bmsBytes > 0) {
                Serial.println(F("  - BMS configuration invalid or incomplete"));
            } else {
                Serial.println(F("  - BMS configuration not found"));
            }
        }
        if (!powerValid) {
            if (powerBytes > 0) {
                Serial.println(F("  - Power configuration invalid or incomplete"));
            } else {
                Serial.println(F("  - Power configuration not found"));
            }
        }
        
        // 恢复默认值并进入配置模式（会自动生成新的identifier）
        resetToDefaults();
        m_isConfigModeRequired = true;
        
        // 保存默认配置到 Flash
        writeToFlash();
        return true;
    }
    
    // 5. 所有检查通过，使用加载的配置
    Serial.println(F("Configuration loaded and validated successfully"));
    systemConfig = loadedSystemConfig;
    bmsConfig = loadedBMSConfig;
    powerConfig = loadedPowerConfig;
    
    // 设置为正常运行模式
    m_isConfigModeRequired = false;
    return false;
}

bool ConfigManager::saveConfiguration() {
    Serial.println(F("Saving all configuration to flash immediately..."));
    return writeToFlash();
}

void ConfigManager::resetWiFiConfig() {
    Serial.println(F("Resetting WiFi configuration to defaults..."));
    
    // 仅重置 WiFi 相关配置，保留其他系统配置
    memset(systemConfig.wifi_ssid, 0, sizeof(systemConfig.wifi_ssid));
    memset(systemConfig.wifi_pass, 0, sizeof(systemConfig.wifi_pass));
    
    // 发布 WiFi 配置变更事件
    EventBus::getInstance().publish(EVT_CONFIG_WIFI_CHANGED, &systemConfig);
    
    // 保存到 Flash
    writeToFlash();
    
}

void ConfigManager::resetConfiguration() {
    Serial.println(F("Resetting configuration to defaults..."));
    
    // Clear flash storage
    preferences.begin("ups_config", false);
    preferences.clear();
    preferences.end();
    
    // Load default values
    resetToDefaults();
    
    // 设置配置模式标志
    m_isConfigModeRequired = true;
}
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

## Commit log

2026-04-28 添加partitions.csv，arduino的自定义的分区文件。
    [partitions.csv]
2026-04-29 更新电池均衡的策略； 修复前端均衡显示的错误； 更新压差过大情况下的soc以及剩余容量的计算。
2026-04-29 更新使用说明
2026-04-30 更新readme
